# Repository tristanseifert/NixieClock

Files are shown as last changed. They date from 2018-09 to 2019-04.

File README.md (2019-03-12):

# Nixie Clock
A Nixie tube clock based on the Russian [IN-12A](http://www.tube-tester.com/sites/nixie/data/in-12a.htm) tubes. The clock is designed to be modular: one or more tube boards (which contain value latches, high voltage drivers, tube mounts, and current limiting resistors) can be connected to the control board (which contains a full 68008-based minicomputer!)

There is also provision for an USB FIFO (FT245R) for communication with a PC, a 32K NVRAM+RTC (DS1244) for timekeeping and configuration, a 100Hz periodic interrupt, and a connection to a Noritake CU24043-Y100 (or any other display with the same pinout) VFD.

The board is powered off of a regulated 12V supply, from which 5V and ~180V (for the anodes) is generated.

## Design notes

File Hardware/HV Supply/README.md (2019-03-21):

# Nixie Clock HV Supply
This power supply is based on Nick de Smith's [Nixie HV Switching PSU](https://www.desmith.net/NMdS/Electronics/NixiePSU.html) and derived from the provided EAGLE files. Modifications were made to use different connectors, and to add Mouser part numbers.

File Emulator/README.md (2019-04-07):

This directory contains source to a simple emulator of the hardware. The emulation is relatively incomplete, and does not emulate some aspects (timings) of the hardware correctly, but it should be good enough to test the basic functioning of code.

It depends on [Musashi](https://github.com/kstenerud/Musashi/) for CPU emulation and disassemblies for logging.

## Usage
Invoke the binary, specifying the required information via these command line flags:

- `-r`: Path to boot ROM file
- `-n`: Path to NVRAM file; created if it doesn't already exist
- `-h`: Prints help

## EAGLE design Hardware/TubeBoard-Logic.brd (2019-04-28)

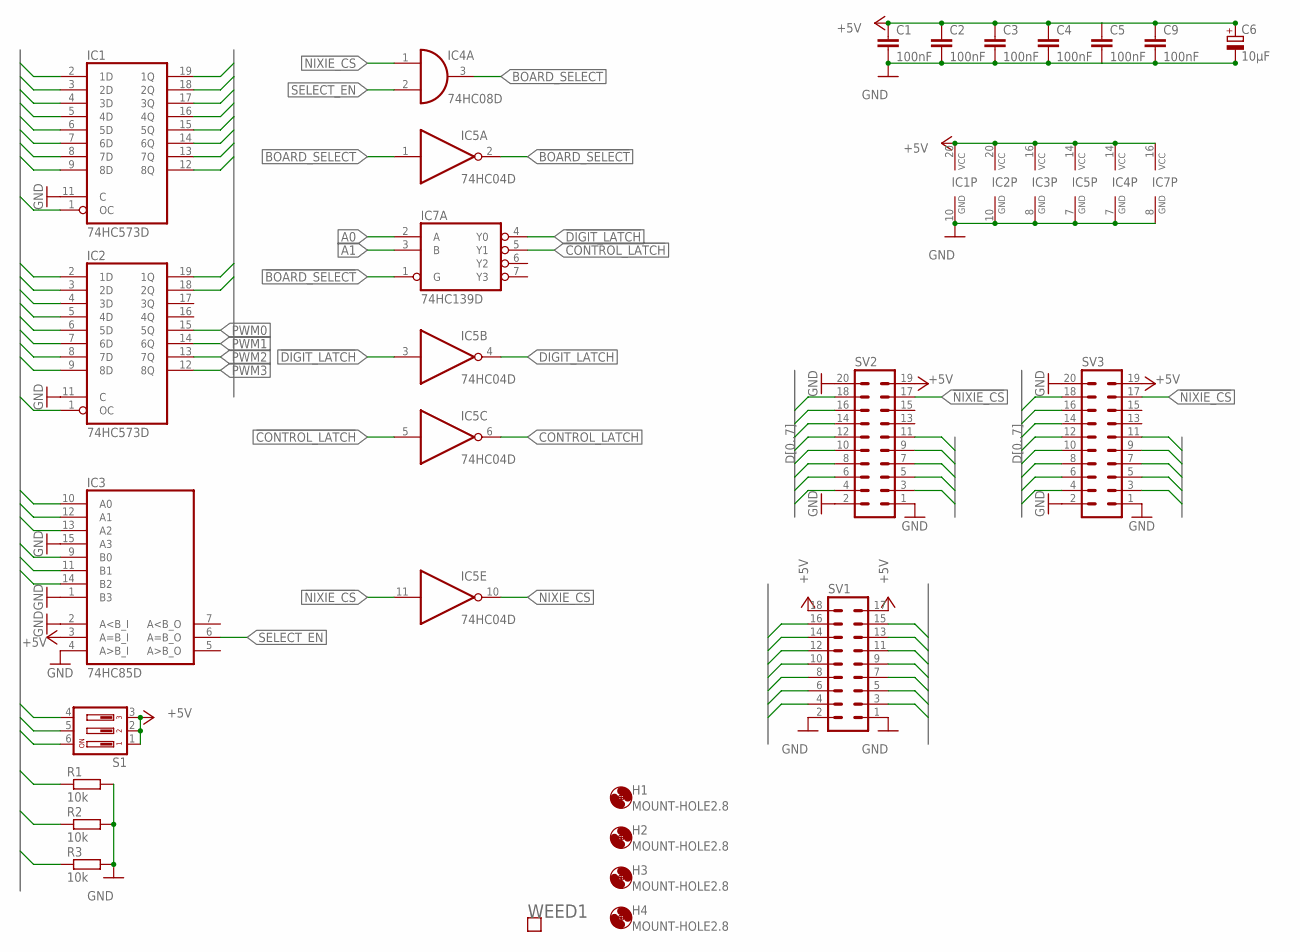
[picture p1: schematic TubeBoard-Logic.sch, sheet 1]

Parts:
C1, C2, C3, C4, C5, C9: 100nF; C1206
C6: 10µF; SMC_B; MOUSER 581-TAJB106K020RNJV
H1, H2, H3, H4: MOUNT-HOLE2.8; 2,8
IC1, IC2: 74HC573D; SO20W
IC3: 74HC85D; SO16; MOUSER 771-74HC85D-T
IC4: 74HC08D; SO14
IC5: 74HC04D; SO14
IC7: 74HC139D; SO16; MOUSER 771-HC139D652
R1, R2, R3: 10k; R2012; MOUSER 652-CR0805FX-1002ELF
S1: SD4-03; MOUSER 611-BDB03
SV1: MA09-2
SV2, SV3: MA10-2
WEED1: WEED; DOINK

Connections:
!BOARD_SELECT: IC5.2 (O), IC7.1 (G)
!CONTROL_LATCH: IC5.5 (I), IC7.5 (Y1)
!DIGIT_LATCH: IC5.3 (I), IC7.4 (Y0)
!NIXIE_CS: IC5.11 (I), SV2.17, SV3.17
+5V: C1.1, C2.1, C3.1, C4.1, C5.1, C6.+, C9.1, IC1.20 (VCC), IC2.20 (VCC), IC3.3 (A=B_I), IC3.16 (VCC), IC4.14 (VCC), IC5.14 (VCC), IC7.16 (VCC), S1.1, S1.2, S1.3, SV1.17, SV1.18, SV2.19, SV3.19
A0: IC7.2 (A), SV2.3, SV3.3
A1: IC7.3 (B), SV2.5, SV3.5
A2: IC3.10 (A0), SV2.7, SV3.7
A3: IC3.12 (A1), SV2.9, SV3.9
A4: IC3.13 (A2), SV2.11, SV3.11
BOARD_SELECT: IC4.3 (O), IC5.1 (I)
COLON_B: IC2.19 (1Q), SV1.8
COLON_T: IC2.18 (2Q), SV1.6
CONTROL_LATCH: IC2.1 (OC), IC5.6 (O)
D0: IC1.2 (1D), IC2.2 (1D), SV2.8, SV3.8
D1: IC1.3 (2D), IC2.3 (2D), SV2.6, SV3.6
D2: IC1.4 (3D), IC2.4 (3D), SV2.4, SV3.4
D3: IC1.5 (4D), IC2.5 (4D), SV2.10, SV3.10
D4: IC1.6 (5D), IC2.6 (5D), SV2.12, SV3.12
D5: IC1.7 (6D), IC2.7 (6D), SV2.14, SV3.14
D6: IC1.8 (7D), IC2.8 (7D), SV2.16, SV3.16
D7: IC1.9 (8D), IC2.9 (8D), SV2.18, SV3.18
DIGIT_LATCH: IC1.1 (OC), IC5.4 (O)
GND: C1.2, C2.2, C3.2, C4.2, C5.2, C6.-, C9.2, IC1.10 (GND), IC1.11 (C), IC2.10 (GND), IC2.11 (C), IC3.1 (B3), IC3.2 (A<B_I), IC3.4 (A>B_I), IC3.8 (GND), IC3.15 (A3), IC4.7 (GND), IC5.7 (GND), IC7.8 (GND), R1.2, R2.2, R3.2, SV1.1, SV1.2, SV2.1, SV2.2, SV2.20, SV3.1, SV3.2, SV3.20; also elsewhere on the board
ID0: IC3.9 (B0), R3.1, S1.6
ID1: IC3.11 (B1), R2.1, S1.5
ID2: IC3.14 (B2), R1.1, S1.4
LDIGIT0: IC1.19 (1Q), SV1.16
LDIGIT1: IC1.18 (2Q), SV1.14
LDIGIT2: IC1.17 (3Q), SV1.12
LDIGIT3: IC1.16 (4Q), SV1.10
NIXIE_CS: IC4.1 (I0), IC5.10 (O)
PWM0: IC2.15 (5Q), SV1.7
PWM1: IC2.14 (6Q), SV1.5
PWM2: IC2.13 (7Q), SV1.3
PWM3: IC2.12 (8Q), SV1.4
RDIGIT0: IC1.15 (5Q), SV1.15
RDIGIT1: IC1.14 (6Q), SV1.13
RDIGIT2: IC1.13 (7Q), SV1.11
RDIGIT3: IC1.12 (8Q), SV1.9
SELECT_EN: IC3.6 (A=B_O), IC4.2 (I1)

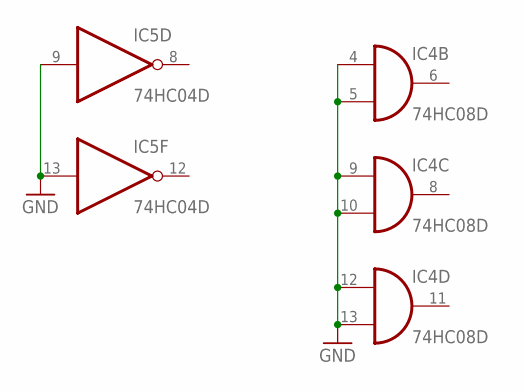
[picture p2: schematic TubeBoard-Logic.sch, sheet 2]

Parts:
IC4: 74HC08D; SO14
IC5: 74HC04D; SO14

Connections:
GND: IC4.4 (I0), IC4.5 (I1), IC4.9 (I0), IC4.10 (I1), IC4.12 (I0), IC4.13 (I1), IC5.9 (I), IC5.13 (I); also elsewhere on the board

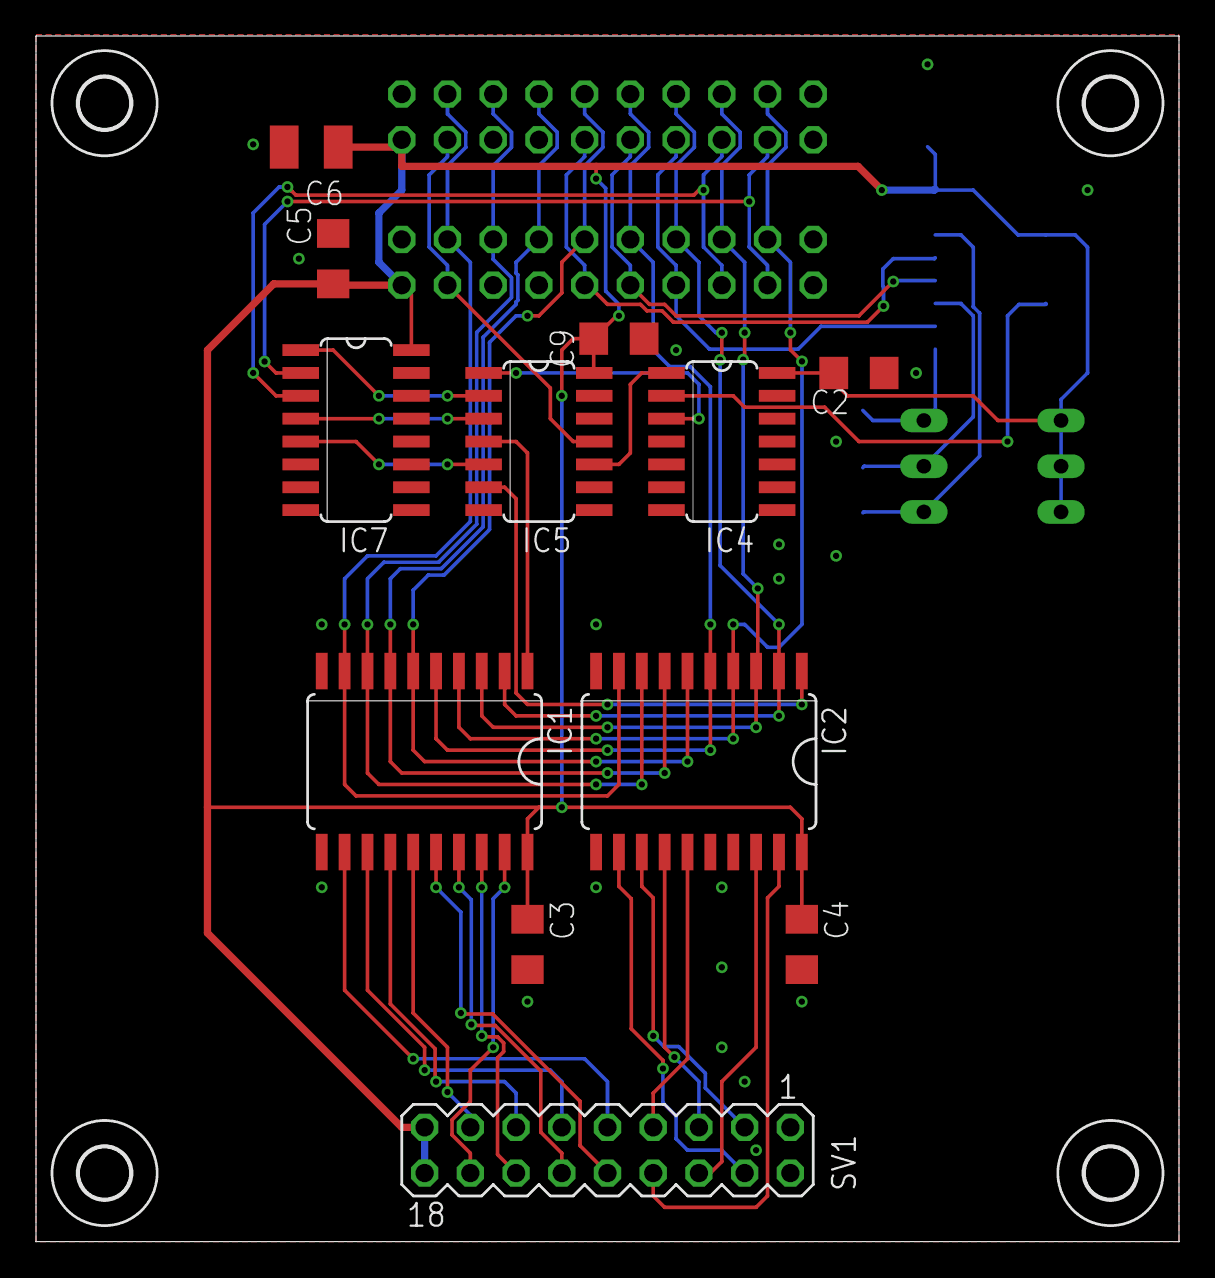
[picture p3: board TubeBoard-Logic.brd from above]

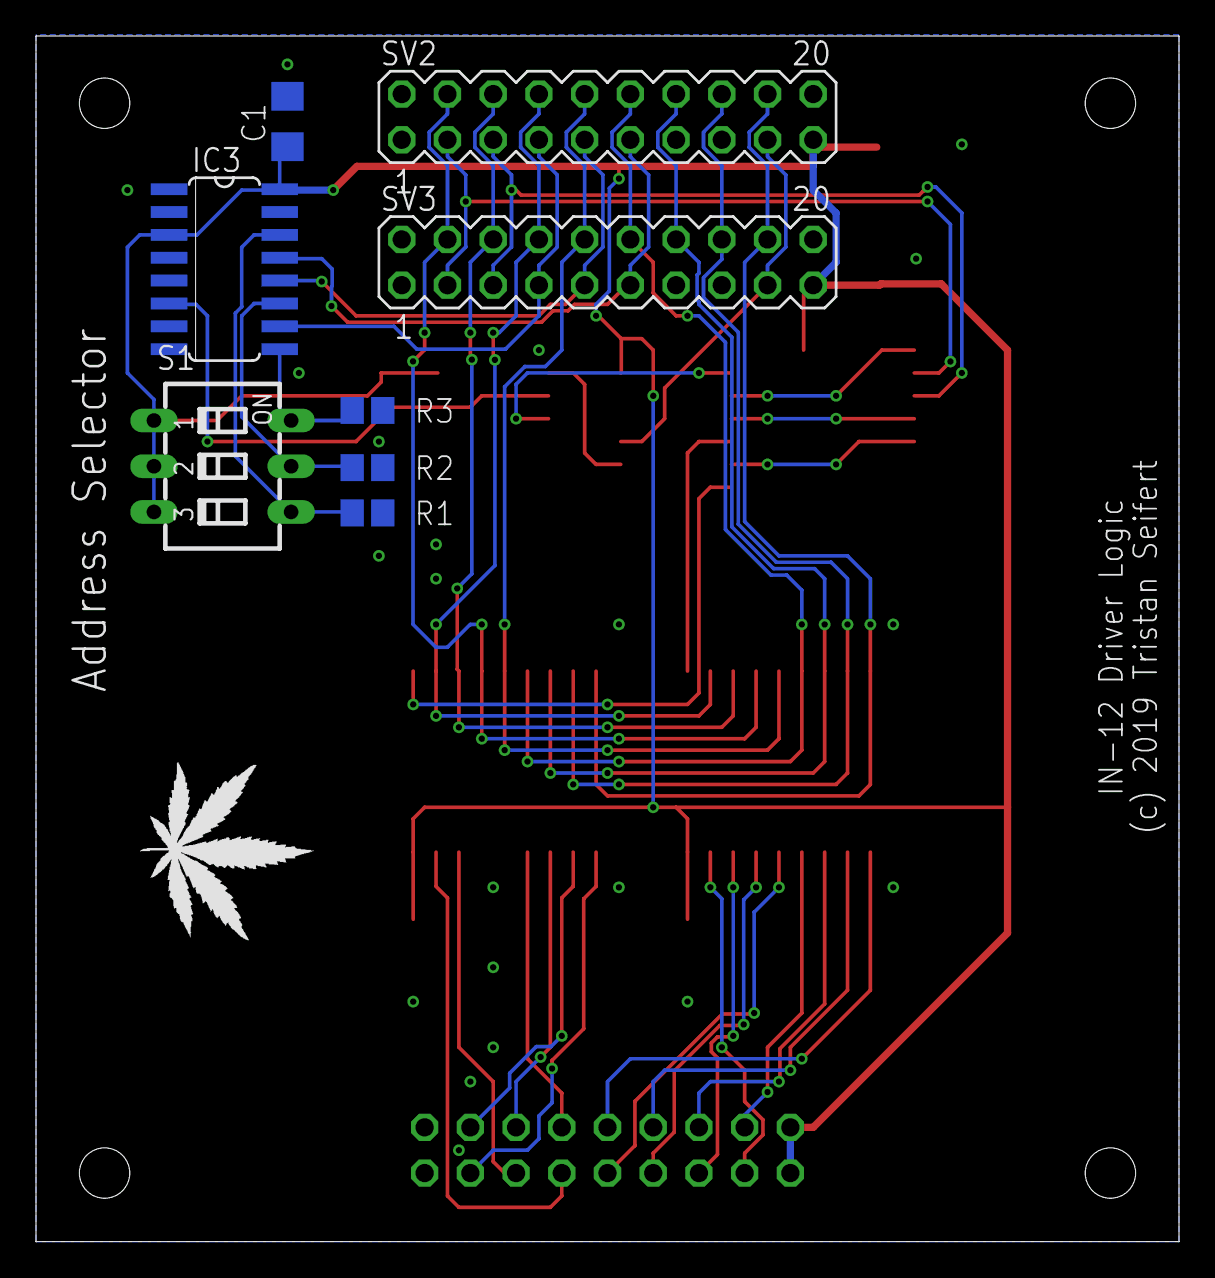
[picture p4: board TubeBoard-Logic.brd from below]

Board: 2 copper layers, 63.5 x 67.0 mm, 25 parts (9 on the bottom side), 41 nets.

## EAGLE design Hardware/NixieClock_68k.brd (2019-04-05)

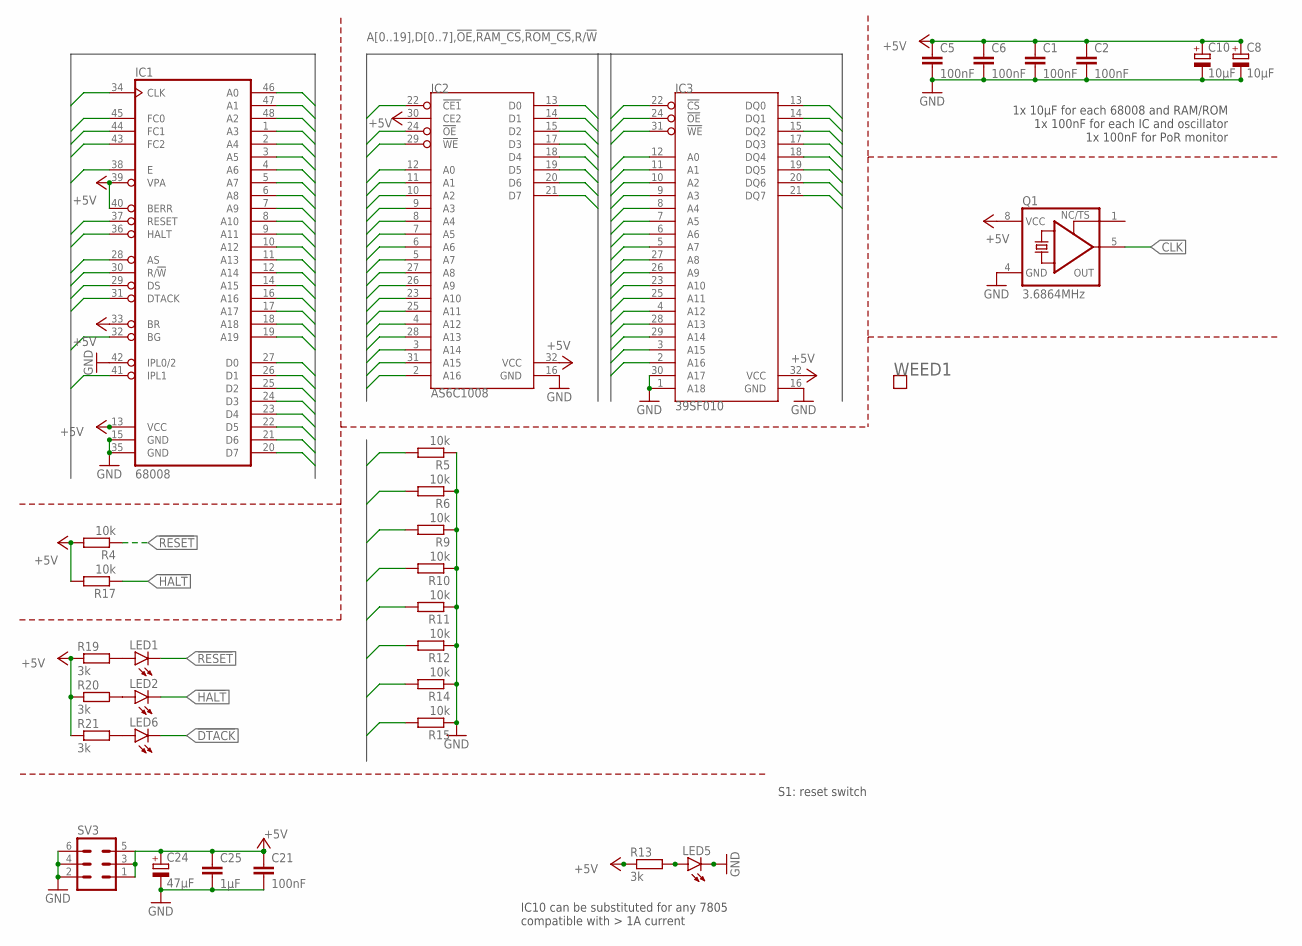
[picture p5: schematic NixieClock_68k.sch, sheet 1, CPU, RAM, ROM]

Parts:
C1, C2, C5, C6, C21: 100nF; C0805; MOUSER 710-885012207072
C8, C10: 10µF; SMC_B; MOUSER 581-TAJB106K020RNJV
C24: 47µF; CT6032; MOUSER 581-TAJD476M016RNJV
C25: 1µF; C0805; MOUSER 710-885012107015
IC1: 68008; DIL48
IC2: AS6C1008; DIL32
IC3: 39SF010; DIL32; MOUSER 804-39SF010A7CPHE
LED1, LED2: LEDCHIPLED_1206; CHIPLED_1206; MOUSER 710-156120RS75300
LED5: LEDCHIPLED_1206; CHIPLED_1206; MOUSER 710-156120YS75300
LED6: LEDCHIPLED_1206; CHIPLED_1206; MOUSER 710-156120VS75300
Q1: 3.6864MHz; DIL08S; MOUSER 774-MXO45HS-3C-3.6
R4, R5, R6, R9, R10, R11, R12, R14, R15, R17: 10k; R2012; MOUSER 652-CR0805FX-1002ELF
R13, R19, R20, R21: 3k; R2012; MOUSER 652-CR0805JW-302ELF
SV3: MA03-2
WEED1: WEED; DOINK

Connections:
!AS: IC1.28 (AS); also elsewhere on the board
!BG: IC1.32 (BG)
!DS: IC1.29 (DS)
!DTACK: IC1.31 (DTACK), LED6.C; also elsewhere on the board
!HALT: IC1.36 (HALT), LED2.C, R17.1; also elsewhere on the board
!IPL1: IC1.41 (IPL1); also elsewhere on the board
!OE: IC2.24 (!OE), IC3.24 (!OE); also elsewhere on the board
!RAM_CS: IC2.22 (!CE1); also elsewhere on the board
!RESET: IC1.37 (RESET), LED1.C, R4.1; also elsewhere on the board
!ROM_CS: IC3.22 (!CS); also elsewhere on the board
+5V: C1.1, C2.1, C5.1, C6.1, C8.+, C10.+, C21.1, C24.+, C25.1, IC1.13 (VCC), IC1.33 (BR), IC1.39 (VPA), IC1.40 (BERR), IC2.30 (CE2), IC2.32 (VCC), IC3.32 (VCC), Q1.8 (VCC), R4.2, R13.1, R17.2, R19.1, R20.1, R21.1, SV3.1, SV3.3, SV3.5; also elsewhere on the board
A0: IC1.46 (A0), IC2.12 (A0), IC3.12 (A0); also elsewhere on the board
A1: IC1.47 (A1), IC2.11 (A1), IC3.11 (A1); also elsewhere on the board
A2: IC1.48 (A2), IC2.10 (A2), IC3.10 (A2); also elsewhere on the board
A3: IC1.1 (A3), IC2.9 (A3), IC3.9 (A3); also elsewhere on the board
A4: IC1.2 (A4), IC2.8 (A4), IC3.8 (A4); also elsewhere on the board
A5: IC1.3 (A5), IC2.7 (A5), IC3.7 (A5); also elsewhere on the board
A6: IC1.4 (A6), IC2.6 (A6), IC3.6 (A6); also elsewhere on the board
A7: IC1.5 (A7), IC2.5 (A7), IC3.5 (A7); also elsewhere on the board
A8: IC1.6 (A8), IC2.27 (A8), IC3.27 (A8); also elsewhere on the board
A9: IC1.7 (A9), IC2.26 (A9), IC3.26 (A9); also elsewhere on the board
A10: IC1.8 (A10), IC2.23 (A10), IC3.23 (A10); also elsewhere on the board
A11: IC1.9 (A11), IC2.25 (A11), IC3.25 (A11); also elsewhere on the board
A12: IC1.10 (A12), IC2.4 (A12), IC3.4 (A12); also elsewhere on the board
A13: IC1.11 (A13), IC2.28 (A13), IC3.28 (A13); also elsewhere on the board
A14: IC1.12 (A14), IC2.3 (A14), IC3.29 (A14); also elsewhere on the board
A15: IC1.14 (A15), IC2.31 (A15), IC3.3 (A15)
A16: IC1.16 (A16), IC2.2 (A16), IC3.2 (A16); also elsewhere on the board
A17: IC1.17 (A17); also elsewhere on the board
A18: IC1.18 (A18); also elsewhere on the board
A19: IC1.19 (A19)
CLK: IC1.34 (CLK), Q1.5 (OUT); also elsewhere on the board
D0: IC1.27 (D0), IC2.13 (D0), IC3.13 (DQ0), R5.2; also elsewhere on the board
D1: IC1.26 (D1), IC2.14 (D1), IC3.14 (DQ1), R6.2; also elsewhere on the board
D2: IC1.25 (D2), IC2.15 (D2), IC3.15 (DQ2), R9.2; also elsewhere on the board
D3: IC1.24 (D3), IC2.17 (D3), IC3.17 (DQ3), R10.2; also elsewhere on the board
D4: IC1.23 (D4), IC2.18 (D4), IC3.18 (DQ4), R11.2; also elsewhere on the board
D5: IC1.22 (D5), IC2.19 (D5), IC3.19 (DQ5), R12.2; also elsewhere on the board
D6: IC1.21 (D6), IC2.20 (D6), IC3.20 (DQ6), R14.2; also elsewhere on the board
D7: IC1.20 (D7), IC2.21 (D7), IC3.21 (DQ7), R15.2; also elsewhere on the board
E: IC1.38 (E)
FC0: IC1.45 (FC0); also elsewhere on the board
FC1: IC1.44 (FC1); also elsewhere on the board
FC2: IC1.43 (FC2); also elsewhere on the board
GND: C1.2, C2.2, C5.2, C6.2, C8.-, C10.-, C21.2, C24.-, C25.2, IC1.15 (GND), IC1.35 (GND), IC1.42 (IPL0/2), IC2.16 (GND), IC3.1 (A18), IC3.16 (GND), IC3.30 (A17), LED5.C, Q1.4 (GND), R5.1, R6.1, R9.1, R10.1, R11.1, R12.1, R14.1, R15.1, SV3.2, SV3.4, SV3.6; also elsewhere on the board
unnamed: LED1.A, R19.2
unnamed: LED5.A, R13.2
unnamed: LED2.A, R20.2
unnamed: LED6.A, R21.2
R/!W!: IC1.30 (R/!W), IC2.29 (!WE), IC3.31 (!WE); also elsewhere on the board

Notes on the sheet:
1x 10µF for each 68008 and RAM/ROM 1x 100nF for each IC and oscillator 1x 100nF for PoR monitor
IC10 can be substituted for any 7805 compatible with > 1A current
S1: reset switch

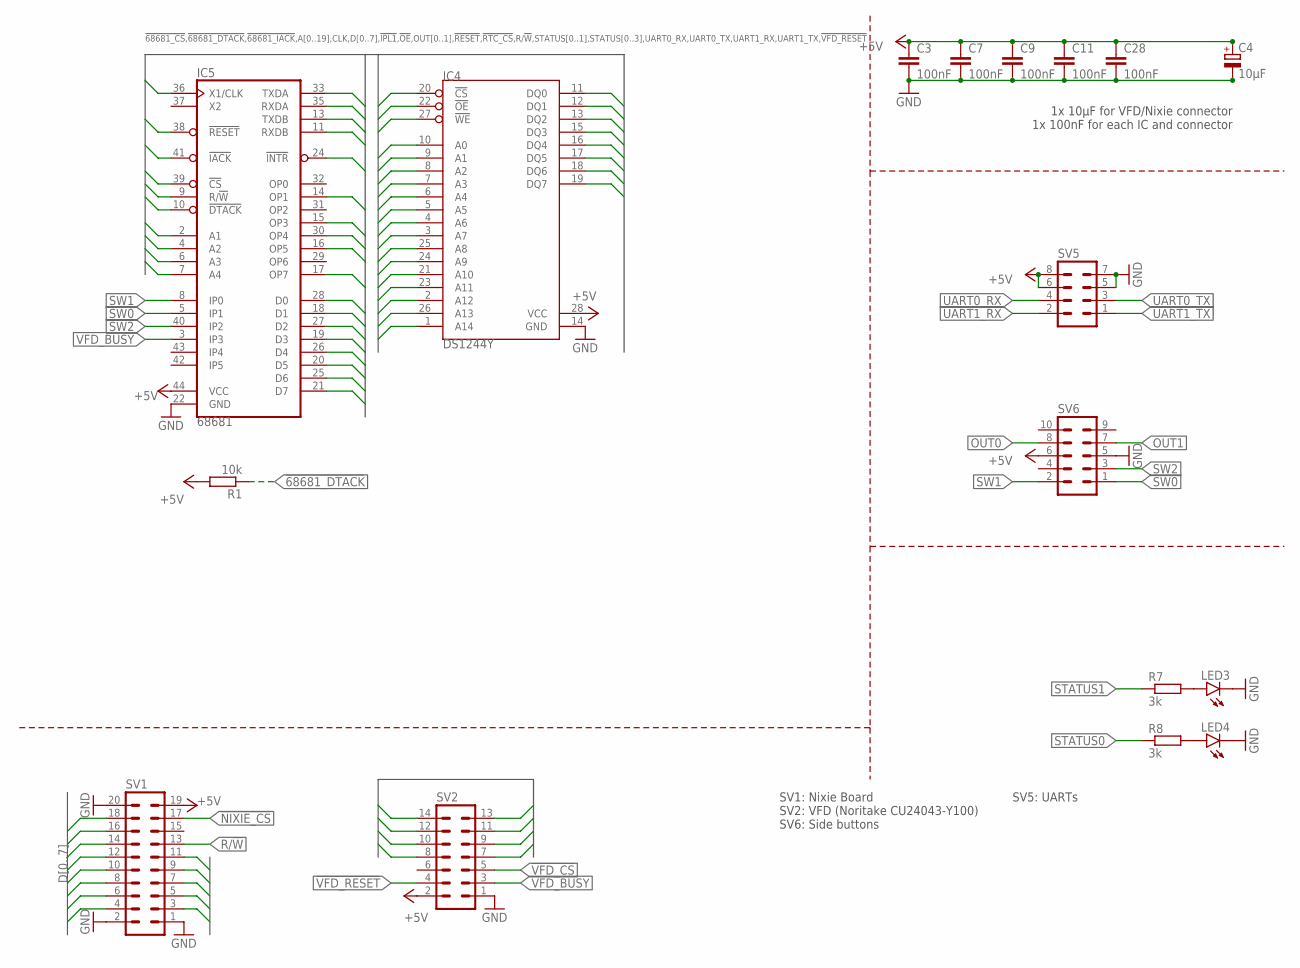
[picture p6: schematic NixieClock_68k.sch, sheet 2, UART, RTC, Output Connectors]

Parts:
C3, C7, C9, C11, C28: 100nF; C0805; MOUSER 710-885012207072
C4: 10µF; SMC_B; MOUSER 581-TAJB106K020RNJV
IC4: DS1244Y; DIL28-6
IC5: 68681; PLCC-S44
LED3, LED4: LEDCHIPLED_1206; CHIPLED_1206; MOUSER 710-156120VS75300
R1: 10k; R2012; MOUSER 652-CR0805FX-1002ELF
R7, R8: 3k; R2012; MOUSER 652-CR0805JW-302ELF
SV1: MA10-2
SV2: MA07-2
SV5: MA04-2
SV6: MA05-2

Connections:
!68681_CS: IC5.39 (!CS); also elsewhere on the board
!68681_DTACK: IC5.10 (!DTACK), R1.1; also elsewhere on the board
!68681_IACK: IC5.41 (!IACK); also elsewhere on the board
!IPL1: IC5.24 (!INTR); also elsewhere on the board
!NIXIE_CS: SV1.17; also elsewhere on the board
!OE: IC4.22 (!OE); also elsewhere on the board
!RESET: IC5.38 (!RESET); also elsewhere on the board
!RTC_CS: IC4.20 (!CS); also elsewhere on the board
!VFD_CS: SV2.5; also elsewhere on the board
!VFD_RESET: IC5.30 (OP4), SV2.4
+5V: C3.1, C4.+, C7.1, C9.1, C11.1, C28.1, IC4.28 (VCC), IC5.44 (VCC), R1.2, SV1.19, SV2.2, SV5.6, SV5.8, SV6.6; also elsewhere on the board
A0: IC4.10 (A0), IC5.2 (A1), SV1.3; also elsewhere on the board
A1: IC4.9 (A1), IC5.4 (A2), SV1.5; also elsewhere on the board
A2: IC4.8 (A2), IC5.6 (A3), SV1.7; also elsewhere on the board
A3: IC4.7 (A3), IC5.7 (A4), SV1.9; also elsewhere on the board
A4: IC4.6 (A4), SV1.11; also elsewhere on the board
A5: IC4.5 (A5); also elsewhere on the board
A6: IC4.4 (A6); also elsewhere on the board
A7: IC4.3 (A7); also elsewhere on the board
A8: IC4.25 (A8); also elsewhere on the board
A9: IC4.24 (A9); also elsewhere on the board
A10: IC4.21 (A10); also elsewhere on the board
A11: IC4.23 (A11); also elsewhere on the board
A12: IC4.2 (A12); also elsewhere on the board
A13: IC4.26 (A13); also elsewhere on the board
A14: IC4.1 (A14); also elsewhere on the board
CLK: IC5.36 (X1/CLK); also elsewhere on the board
D0: IC4.11 (DQ0), IC5.28 (D0), SV1.8, SV2.7; also elsewhere on the board
D1: IC4.12 (DQ1), IC5.18 (D1), SV1.6, SV2.8; also elsewhere on the board
D2: IC4.13 (DQ2), IC5.27 (D2), SV1.4, SV2.9; also elsewhere on the board
D3: IC4.15 (DQ3), IC5.19 (D3), SV1.10, SV2.10; also elsewhere on the board
D4: IC4.16 (DQ4), IC5.26 (D4), SV1.12, SV2.11; also elsewhere on the board
D5: IC4.17 (DQ5), IC5.20 (D5), SV1.14, SV2.12; also elsewhere on the board
D6: IC4.18 (DQ6), IC5.25 (D6), SV1.16, SV2.13; also elsewhere on the board
D7: IC4.19 (DQ7), IC5.21 (D7), SV1.18, SV2.14; also elsewhere on the board
GND: C3.2, C4.-, C7.2, C9.2, C11.2, C28.2, IC4.14 (GND), IC5.22 (GND), LED3.C, LED4.C, SV1.1, SV1.2, SV1.20, SV2.1, SV5.5, SV5.7, SV6.5; also elsewhere on the board
unnamed: LED3.A, R7.2
unnamed: LED4.A, R8.2
OUT0: IC5.15 (OP3), SV6.8
OUT1: IC5.14 (OP1), SV6.7
R/!W!: IC4.27 (!WE), IC5.9 (R/!W), SV1.13; also elsewhere on the board
STATUS0: IC5.17 (OP7), R8.1
STATUS1: IC5.16 (OP5), R7.1
SW0: IC5.5 (IP1), SV6.1
SW1: IC5.8 (IP0), SV6.2
SW2: IC5.40 (IP2), SV6.3
UART0_RX: IC5.35 (RXDA), SV5.4
UART0_TX: IC5.33 (TXDA), SV5.3
UART1_RX: IC5.11 (RXDB), SV5.2
UART1_TX: IC5.13 (TXDB), SV5.1
VFD_BUSY: IC5.3 (IP3), SV2.3

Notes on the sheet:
SV1: Nixie Board SV2: VFD (Noritake CU24043-Y100) SV6: Side buttons
1x 10µF for VFD/Nixie connector 1x 100nF for each IC and connector
SV5: UARTs

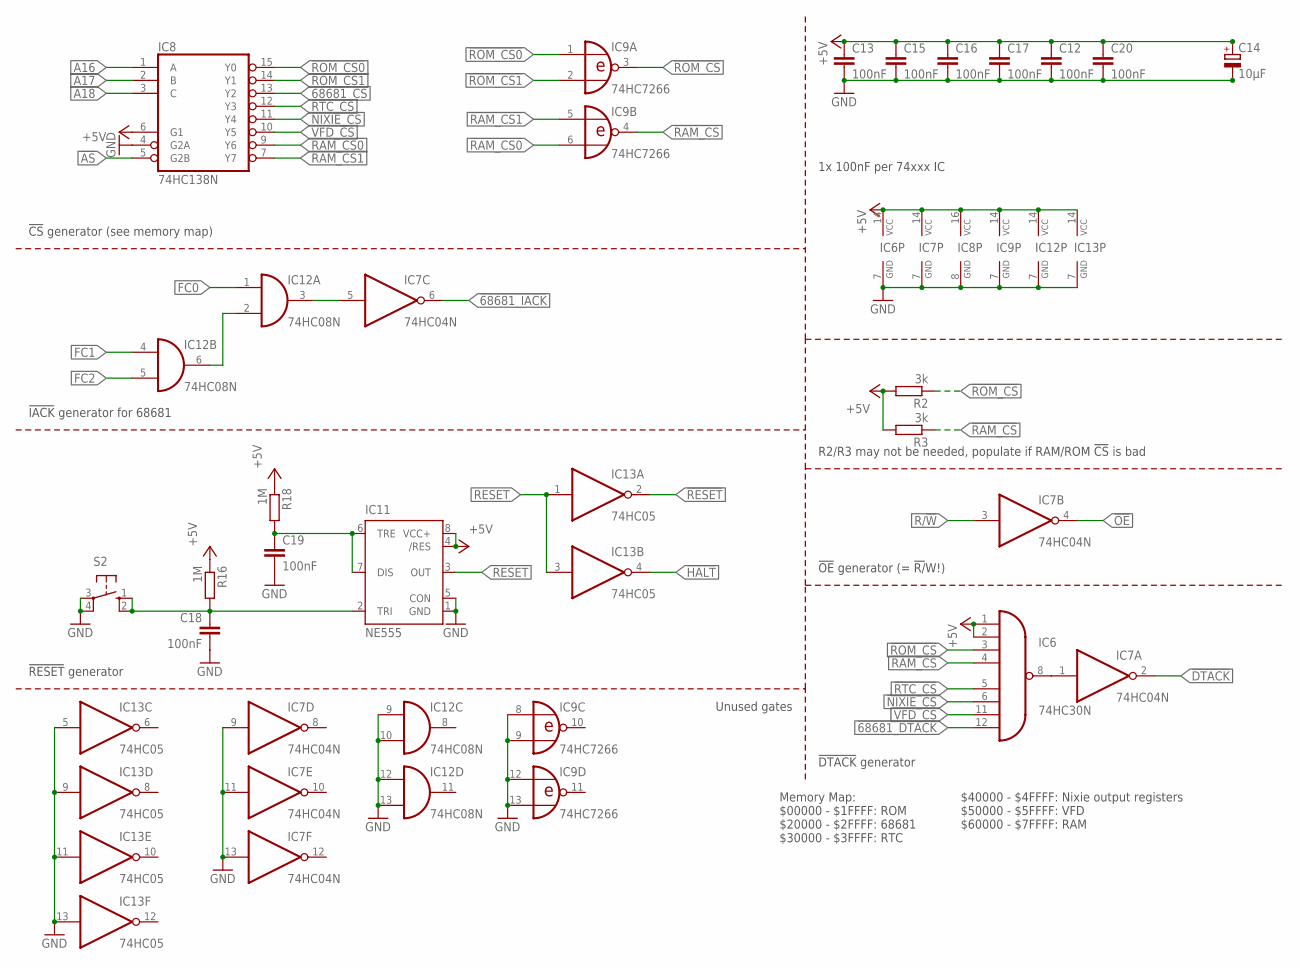
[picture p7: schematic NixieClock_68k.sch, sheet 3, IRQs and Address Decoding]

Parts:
C12, C13, C15, C16, C17, C18, C20: 100nF; C0805; MOUSER 710-885012207072
C14: 10µF; SMC_B; MOUSER 581-TAJB106K020RNJV
C19: 100nF; C0805; MOUSER 710-885012207078
IC6: 74HC30N; DIL14; MOUSER 595-CD74HC30E
IC7: 74HC04N; DIL14; MOUSER 595-SN74HC04AN
IC8: 74HC138N; DIL16; MOUSER 595-SN74HC138N
IC9: 74HC7266; DIL14; MOUSER 595-CD74HC7266E
IC11: NE555; DIL-08; MOUSER 595-NE555P
IC12: 74HC08N; DIL14; MOUSER 595-SN74HC08AN
IC13: 74HC05; DIL14; MOUSER 595-SN74HC05N
R2, R3: 3k; R2012; MOUSER 652-CR0805JW-302ELF
R16, R18: 1M; R2012; MOUSER 652-CR0805FX-18R2ELF
S2: 10-XX; B3F-10XX; MOUSER 653-B3F-1052

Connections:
!68681_CS: IC8.13 (Y2); also elsewhere on the board
!68681_DTACK: IC6.12 (I7); also elsewhere on the board
!68681_IACK: IC7.6 (O); also elsewhere on the board
!AS: IC8.5 (G2B); also elsewhere on the board
!DTACK: IC7.2 (O); also elsewhere on the board
!HALT: IC13.4 (O); also elsewhere on the board
!NIXIE_CS: IC6.6 (I5), IC8.11 (Y4); also elsewhere on the board
!OE: IC7.4 (O); also elsewhere on the board
!RAM_CS: IC6.4 (I3), IC9.4 (O), R3.1; also elsewhere on the board
!RAM_CS0: IC8.9 (Y6), IC9.6 (I1)
!RAM_CS1: IC8.7 (Y7), IC9.5 (I0)
!RESET: IC13.2 (O); also elsewhere on the board
!ROM_CS: IC6.3 (I2), IC9.3 (O), R2.1; also elsewhere on the board
!ROM_CS0: IC8.15 (Y0), IC9.1 (I0)
!ROM_CS1: IC8.14 (Y1), IC9.2 (I1)
!RTC_CS: IC6.5 (I4), IC8.12 (Y3); also elsewhere on the board
!VFD_CS: IC6.11 (I6), IC8.10 (Y5); also elsewhere on the board
+5V: C12.1, C13.1, C14.+, C15.1, C16.1, C17.1, C20.1, IC6.1 (I0), IC6.2 (I1), IC6.14 (VCC), IC7.14 (VCC), IC8.6 (G1), IC8.16 (VCC), IC9.14 (VCC), IC11.4 (/RES), IC11.8 (VCC+), IC12.14 (VCC), IC13.14 (VCC), R2.2, R3.2, R16.1, R18.1; also elsewhere on the board
A16: IC8.1 (A); also elsewhere on the board
A17: IC8.2 (B); also elsewhere on the board
A18: IC8.3 (C); also elsewhere on the board
FC0: IC12.1 (I0); also elsewhere on the board
FC1: IC12.4 (I0); also elsewhere on the board
FC2: IC12.5 (I1); also elsewhere on the board
GND: C12.2, C13.2, C14.-, C15.2, C16.2, C17.2, C18.2, C19.2, C20.2, IC6.7 (GND), IC7.7 (GND), IC7.9 (I), IC7.11 (I), IC7.13 (I), IC8.4 (G2A), IC8.8 (GND), IC9.7 (GND), IC9.8 (I0), IC9.9 (I1), IC9.12 (I0), IC9.13 (I1), IC11.1 (GND), IC11.5 (CON), IC12.7 (GND), IC12.9 (I0), IC12.10 (I1), IC12.12 (I0), IC12.13 (I1), IC13.5 (I), IC13.7 (GND), IC13.9 (I), IC13.11 (I), IC13.13 (I), S2.3, S2.4 (P1); also elsewhere on the board
unnamed: C18.1, IC11.2 (TRI), R16.2, S2.1 (S), S2.2 (S1)
unnamed: IC6.8 (O), IC7.1 (I)
unnamed: IC7.5 (I), IC12.3 (O)
unnamed: IC12.2 (I1), IC12.6 (O)
unnamed: C19.1, IC11.6 (TRE), IC11.7 (DIS), R18.2
R/!W!: IC7.3 (I); also elsewhere on the board
RESET: IC11.3 (OUT), IC13.1 (I), IC13.3 (I)

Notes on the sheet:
Memory Map: $00000 - $1FFFF: ROM $20000 - $2FFFF: 68681 $30000 - $3FFFF: RTC
1x 100nF per 74xxx IC
!DTACK! generator
!OE! generator (= !R/!W!)
!CS! generator (see memory map)
!IACK! generator for 68681
$40000 - $4FFFF: Nixie output registers $50000 - $5FFFF: VFD $60000 - $7FFFF: RAM
!RESET! generator
Unused gates
R2/R3 may not be needed, populate if RAM/ROM !CS! is bad

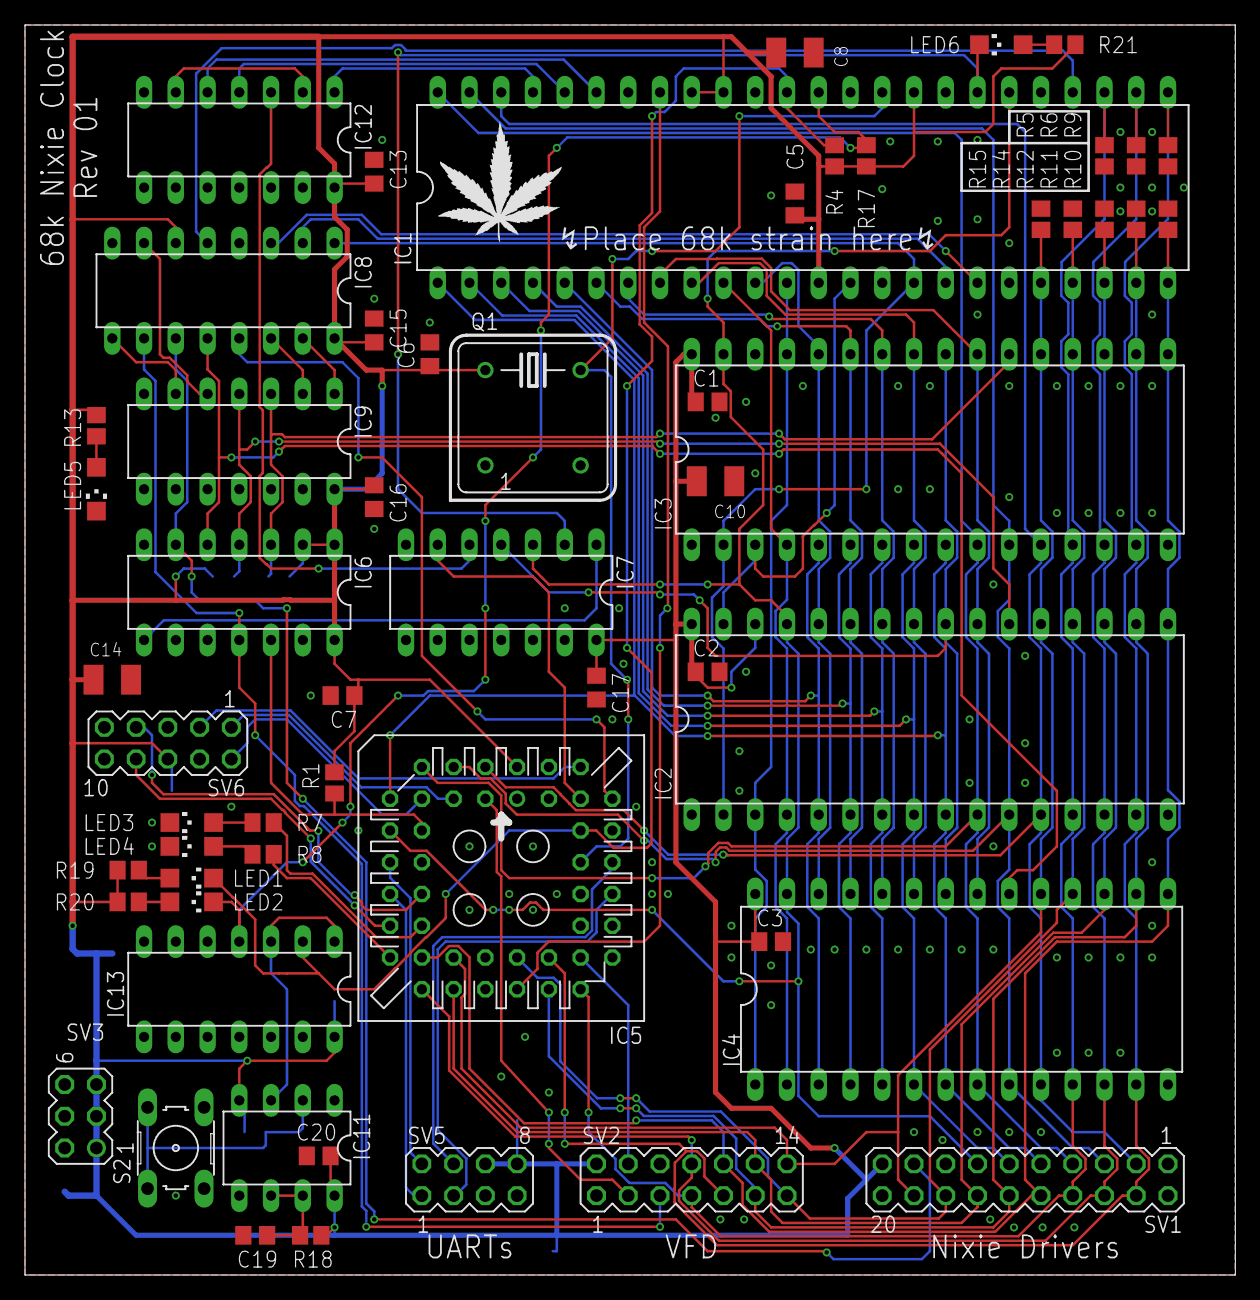
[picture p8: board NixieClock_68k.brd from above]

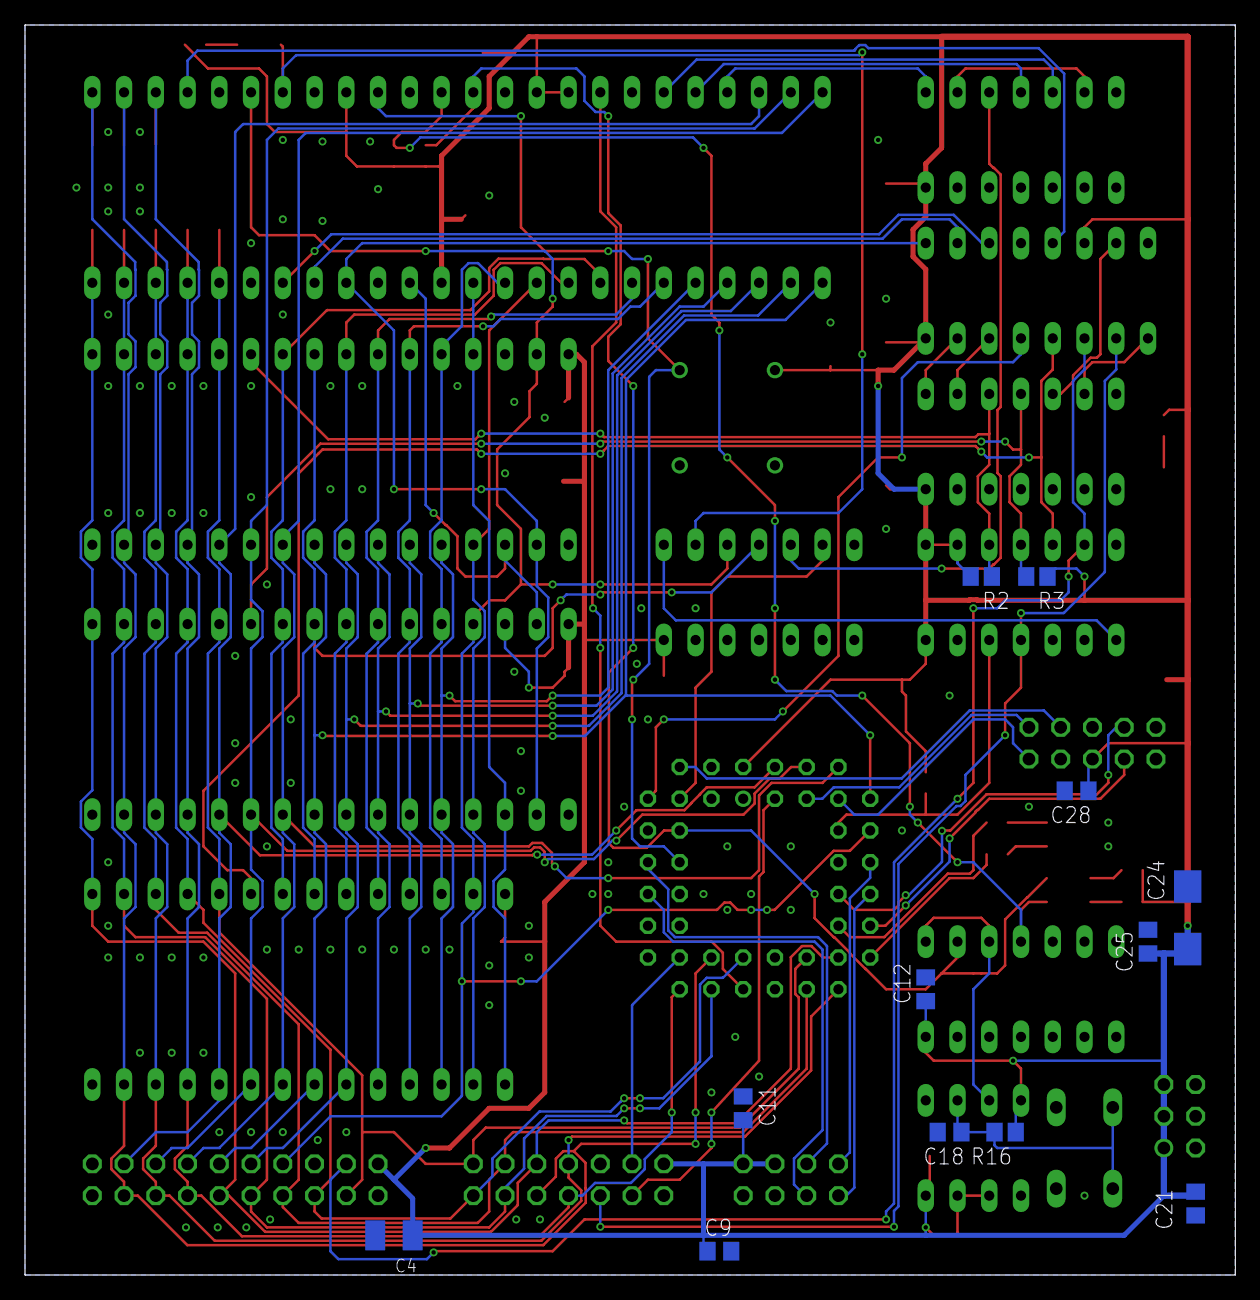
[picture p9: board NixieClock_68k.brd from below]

Board: 2 copper layers, 96.8 x 100.0 mm, 71 parts (12 on the bottom side), 77 nets.

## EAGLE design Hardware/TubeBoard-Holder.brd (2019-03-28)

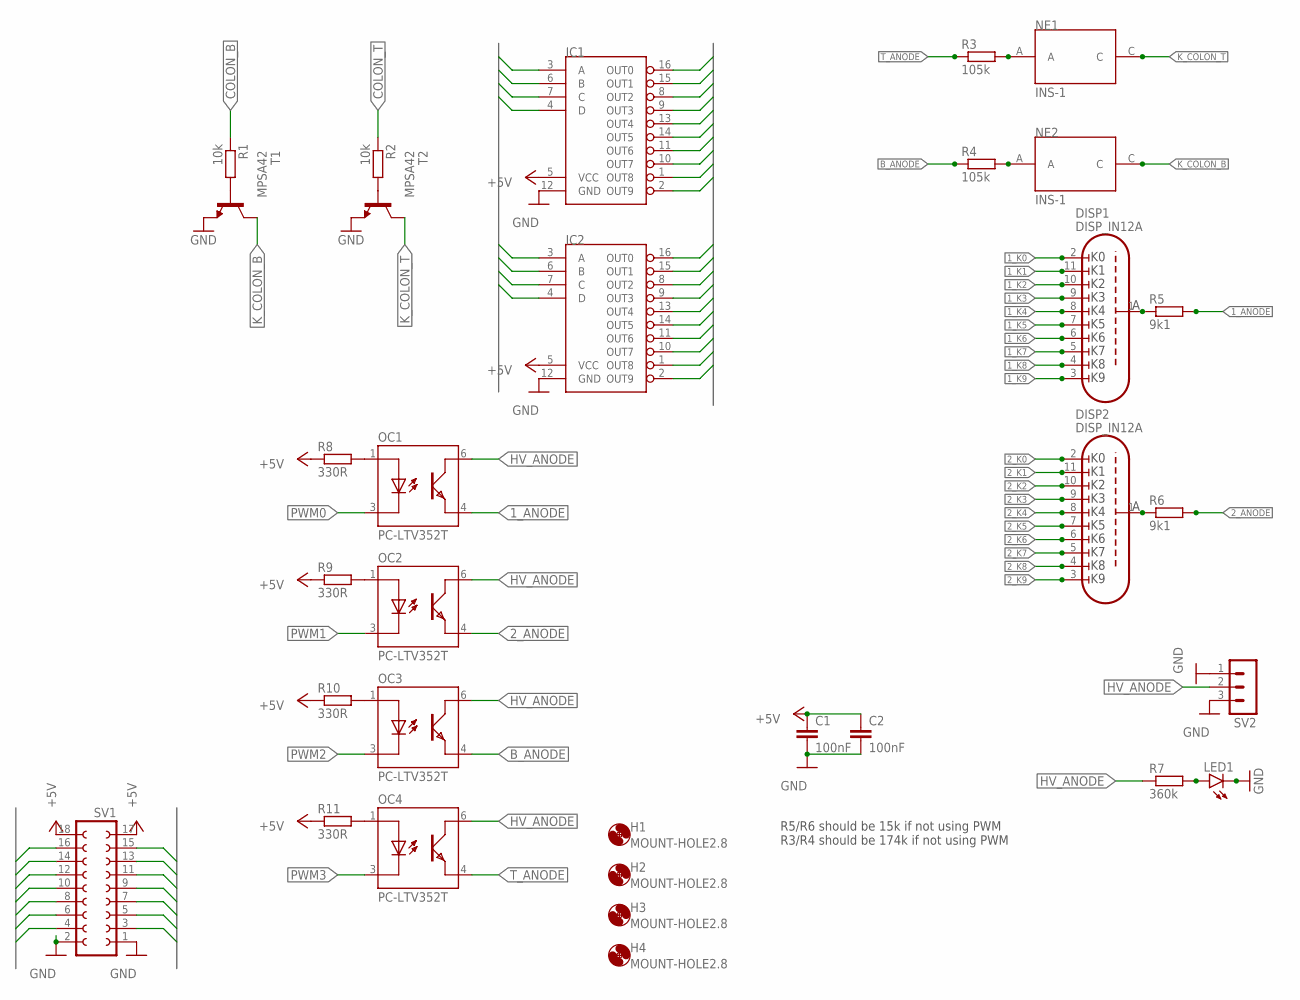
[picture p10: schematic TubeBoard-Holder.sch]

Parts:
C1, C2: 100nF; C1206
DISP1, DISP2: DISP_IN12A; DISP_IN-12_SOCKET
H1, H2, H3, H4: MOUNT-HOLE2.8; 2,8
IC1, IC2: 7441DIL16; DIL16
LED1: LEDCHIPLED_1206; CHIPLED_1206; MOUSER 710-156120RS75300
NE1, NE2: INS-1
OC1, OC2, OC3, OC4: PC-LTV352T; MINIFLAT4; MOUSER 859-LTV-352T
R1, R2: 10k; R2012; MOUSER 652-CR0805FX-1002ELF
R3, R4: 105k; M1206; MOUSER 667-ERJ-8ENF1053V
R5, R6: 9k1; 0411/12
R7: 360k; R2012; MOUSER 652-CR0805-JW-364ELF
R8, R9, R10, R11: 330R; R2012; MOUSER 652-CR0805FX-3300ELF
SV1: FE09-2
SV2: MA03-1
T1, T2: MPSA42; TO92-EBC; MOUSER 833-MPSA42-AP

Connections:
1_ANODE: OC1.4 (TE), R5.2
1_K0: DISP1.2 (K0), IC1.16 (OUT0)
1_K1: DISP1.11 (K1), IC1.15 (OUT1)
1_K2: DISP1.10 (K2), IC1.8 (OUT2)
1_K3: DISP1.9 (K3), IC1.9 (OUT3)
1_K4: DISP1.8 (K4), IC1.13 (OUT4)
1_K5: DISP1.7 (K5), IC1.14 (OUT5)
1_K6: DISP1.6 (K6), IC1.11 (OUT6)
1_K7: DISP1.5 (K7), IC1.10 (OUT7)
1_K8: DISP1.4 (K8), IC1.1 (OUT8)
1_K9: DISP1.3 (K9), IC1.2 (OUT9)
2_ANODE: OC2.4 (TE), R6.2
2_K0: DISP2.2 (K0), IC2.16 (OUT0)
2_K1: DISP2.11 (K1), IC2.15 (OUT1)
2_K2: DISP2.10 (K2), IC2.8 (OUT2)
2_K3: DISP2.9 (K3), IC2.9 (OUT3)
2_K4: DISP2.8 (K4), IC2.13 (OUT4)
2_K5: DISP2.7 (K5), IC2.14 (OUT5)
2_K6: DISP2.6 (K6), IC2.11 (OUT6)
2_K7: DISP2.5 (K7), IC2.10 (OUT7)
2_K8: DISP2.4 (K8), IC2.1 (OUT8)
2_K9: DISP2.3 (K9), IC2.2 (OUT9)
+5V: C1.1, C2.1, IC1.5 (VCC), IC2.5 (VCC), R8.1, R9.1, R10.1, R11.1, SV1.17, SV1.18
B_ANODE: OC3.4 (TE), R4.1
COLON_B: R1.1, SV1.8
COLON_T: R2.1, SV1.6
GND: C1.2, C2.2, IC1.12 (GND), IC2.12 (GND), LED1.C, SV1.1, SV1.2, SV2.1, SV2.3, T1.E, T2.E
HV_ANODE: OC1.6 (TC), OC2.6 (TC), OC3.6 (TC), OC4.6 (TC), R7.1, SV2.2
K_COLON_B: NE2.C, T1.C
K_COLON_T: NE1.C, T2.C
LDIGIT0: IC1.3 (A), SV1.16
LDIGIT1: IC1.6 (B), SV1.14
LDIGIT2: IC1.7 (C), SV1.12
LDIGIT3: IC1.4 (D), SV1.10
unnamed: DISP1.1 (ANODE), R5.1
unnamed: DISP2.1 (ANODE), R6.1
unnamed: NE1.A, R3.2
unnamed: NE2.A, R4.2
unnamed: R1.2, T1.B
unnamed: R2.2, T2.B
unnamed: OC1.1 (A), R8.2
unnamed: LED1.A, R7.2
unnamed: OC2.1 (A), R9.2
unnamed: OC3.1 (A), R10.2
unnamed: OC4.1 (A), R11.2
PWM0: OC1.3 (C), SV1.7
PWM1: OC2.3 (C), SV1.5
PWM2: OC3.3 (C), SV1.3
PWM3: OC4.3 (C), SV1.4
RDIGIT0: IC2.3 (A), SV1.15
RDIGIT1: IC2.6 (B), SV1.13
RDIGIT2: IC2.7 (C), SV1.11
RDIGIT3: IC2.4 (D), SV1.9
T_ANODE: OC4.4 (TE), R3.1

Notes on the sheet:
R5/R6 should be 15k if not using PWM R3/R4 should be 174k if not using PWM

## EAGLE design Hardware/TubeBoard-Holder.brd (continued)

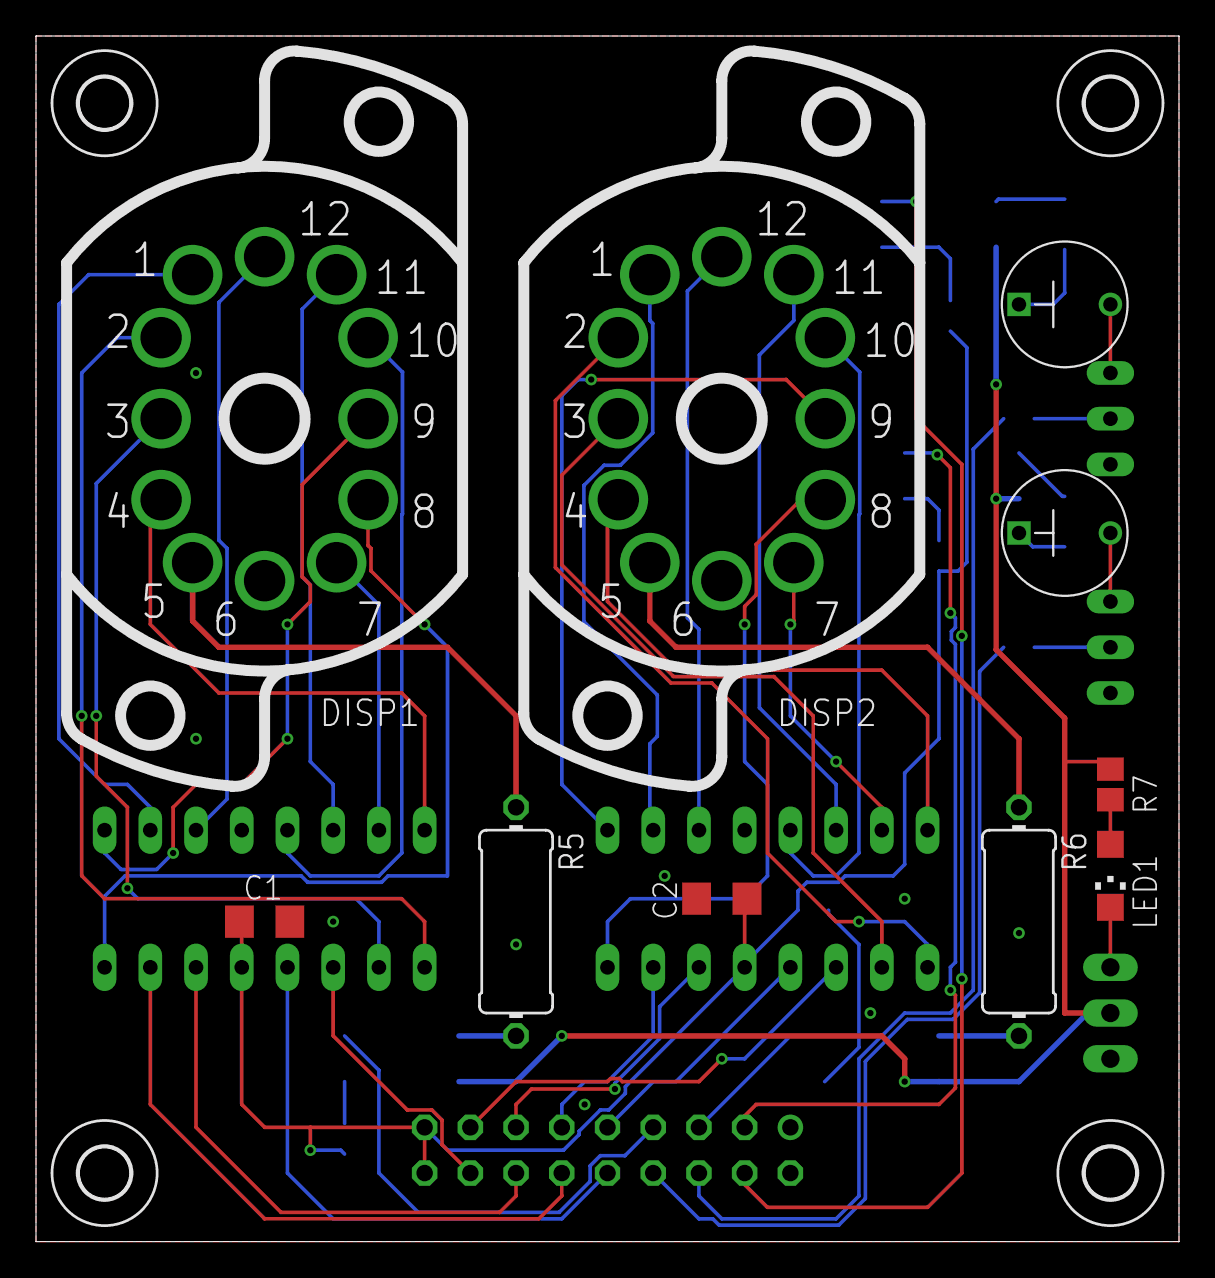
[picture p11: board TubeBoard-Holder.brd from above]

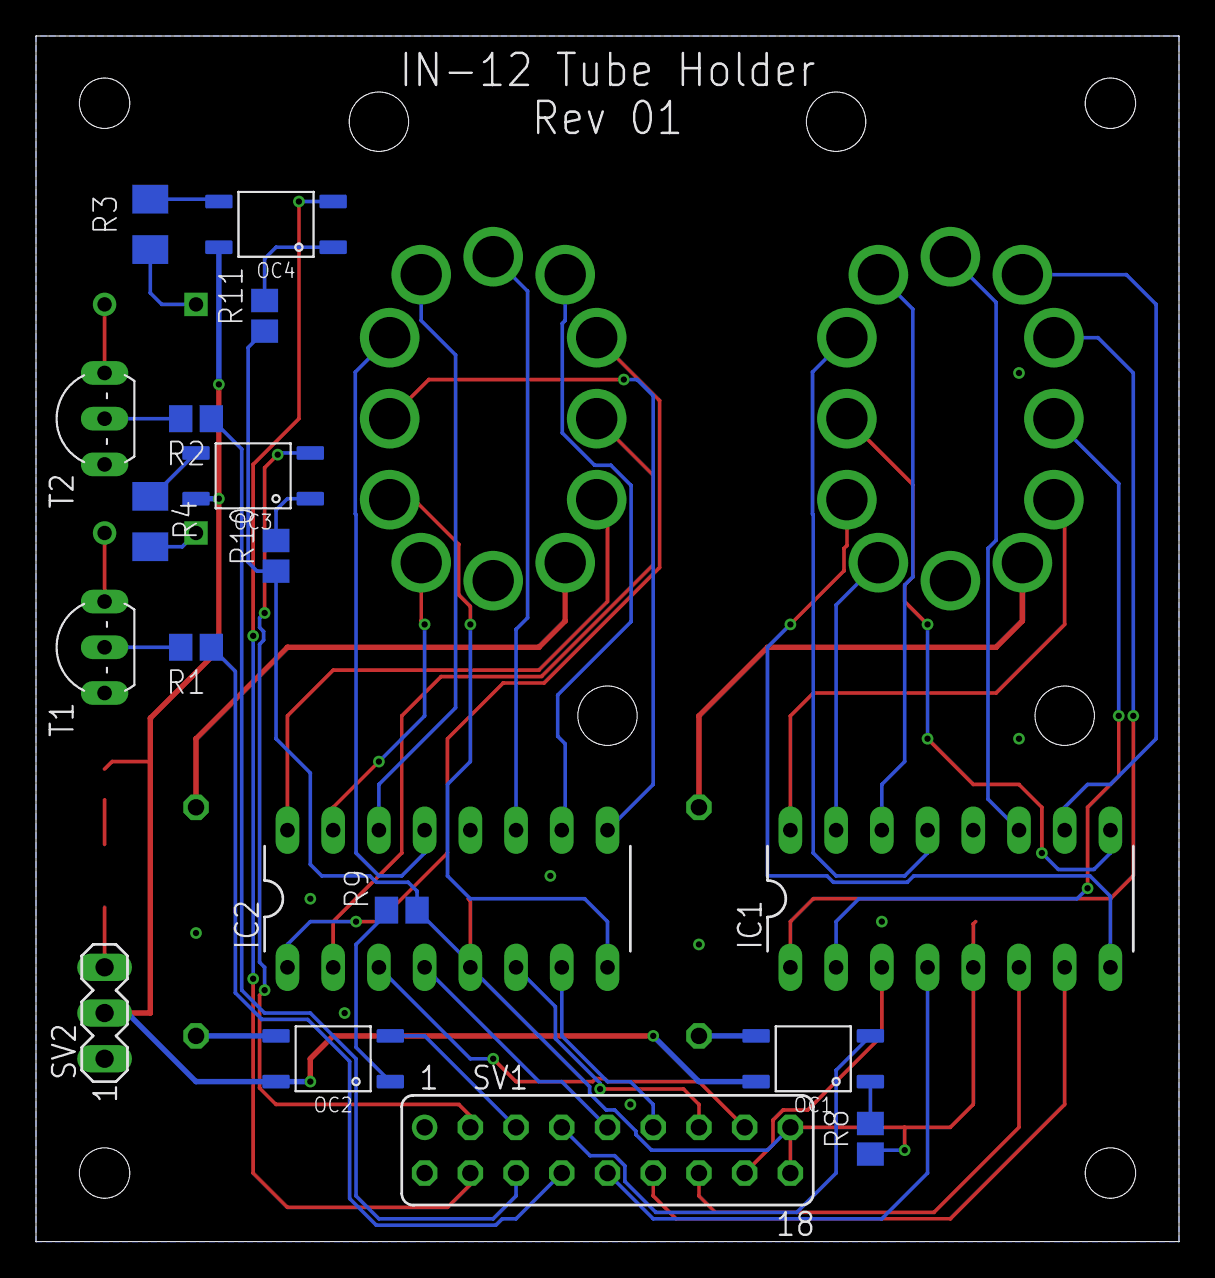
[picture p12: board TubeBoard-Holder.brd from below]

Board: 2 copper layers, 63.5 x 67.0 mm, 32 parts (18 on the bottom side), 54 nets.

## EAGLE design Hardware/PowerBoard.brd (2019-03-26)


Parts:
C101, C102, C103, C104: 2.2µF; C0805; MOUSER 710-885012107016
C105, C106: 100nF; C0805; MOUSER 710-885012207072
C107: 10µF; SMC_B; MOUSER 581-TAJB106K020RNJV
H101, H102, H103: MOUNT-HOLE2.8; 2,8
IC101: MAX232; DIL16; MOUSER 595-MAX232N
S101: DP04; DP-04; MOUSER 611-BDB04
SV101, SV102: MA04-2
X101, X102: F09HPS; F09HP

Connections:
+5V: C105.1, C106.1, C107.+, IC101.16 (VCC), SV102.6, SV102.8; also elsewhere on the board
GND: C103.2, C104.2, C105.2, C106.2, C107.-, IC101.15 (GND), SV101.5, SV101.7, SV102.5, SV102.7, X101.5 (F), X101.G1, X102.5 (F), X102.G1; also elsewhere on the board
unnamed: C104.1, IC101.2 (V+)
unnamed: C103.1, IC101.6 (V-)
unnamed: C102.1, IC101.4 (C2+)
unnamed: C101.1, IC101.1 (C1+)
unnamed: SV101.6, SV101.8
unnamed: IC101.9 (R2OUT), S101.5
unnamed: C102.2, IC101.5 (C2-)
unnamed: C101.2, IC101.3 (C1-)
unnamed: IC101.12 (R1OUT), S101.6
unnamed: IC101.10 (T2IN), S101.7
unnamed: IC101.11 (T1IN), S101.8
SER0_IN: IC101.13 (R1IN), X101.3 (F)
SER0_OUT: IC101.14 (T1OUT), X101.2 (F)
SER1_IN: IC101.8 (R2IN), X102.3 (F)
SER1_OUT: IC101.7 (T2OUT), X102.2 (F)
UART0_RX: S101.3, SV101.4, SV102.4
UART0_TX: S101.1, SV101.3, SV102.3
UART1_RX: S101.4, SV101.2, SV102.2
UART1_TX: S101.2, SV101.1, SV102.1

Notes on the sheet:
X101: UART0 RS232 X102: UART1 RS232
SV101: UART from CPU board SV102: UART at TTL level Use DIP switch S101 to select which UARTs are TTL or RS232 level


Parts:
C201: 100nF; C0805; MOUSER 710-885012207072
C202, C204, C205, C206, C207: 1µF; C0805; MOUSER 710-885012107015
C203: 47µF; CT6032; MOUSER 581-TAJD476M016RNJV
IC201: 7805; TO220V; MOUSER 490-VXO7805-1000
LED201, LED202: LEDCHIPLED_1206; CHIPLED_1206; MOUSER 710-156120YS75300
R201: 10k; R2012; MOUSER 652-CR0805FX-1002ELF
R202: 3k; R2012; MOUSER 652-CR0805JW-302ELF
SV201: 1792863
SV202: MA04-2
SV203, SV204: MA03-2

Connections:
+5V: C203.+, C204.1, C205.1, C206.1, C207.1, IC201.3 (VO), R202.1, SV202.1, SV203.1, SV203.3, SV203.5, SV204.1, SV204.3, SV204.5; also elsewhere on the board
+12V: C201.1, C202.1, IC201.1 (VI), R201.1, SV201.2, SV202.3, SV202.5, SV202.7
GND: C201.2, C202.2, C203.-, C204.2, C205.2, C206.2, C207.2, IC201.2 (GND), LED201.C, LED202.C, SV201.1, SV202.2, SV202.4, SV202.6, SV202.8, SV203.2, SV203.4, SV203.6, SV204.2, SV204.4, SV204.6; also elsewhere on the board
unnamed: LED202.A, R202.2
unnamed: LED201.A, R201.2

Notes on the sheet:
SV201: +12VDC input SV202: To HV supply SV203-204: Regulated 5V



Board: 2 copper layers, 97.0 x 38.1 mm, 32 parts (9 on the bottom side), 24 nets.

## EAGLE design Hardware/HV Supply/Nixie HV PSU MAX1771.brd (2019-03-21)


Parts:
C1: 100uF,35V; C-EIA-7343; MOUSER 581-TPSD107M020R0085
C2, C3: 100n; C0805; MOUSER 80-C0805C104M4V
C4: 4u7,250V; NICHICON-UJ-12; MOUSER 667-EEV-EB2E100Q
C5: 10uF,25V; C-EIA-7343; MOUSER 581-TPSD106K035R0300
C6: 100n,250V; C2420; MOUSER 667-ECW-U2104KC9
D1: ES2F; SMC; MOUSER 821-ES2FR5
IC1: MAX1771ESA; SO-8; MOUSER 700-MAX1771ESAT
J3: TERM-BLOCK-2-02IN; SCREW-2-02
L1: 100uH; L-B82479; MOUSER 871-B82479A1104M
R1: 10K; R0805; MOUSER 71-CRCW080510K0FKEAC
R2: 1M5; R2512; MOUSER 279-35221M5JT
RSENSE: 0R050; R2010; MOUSER 66-LR2010LF-01-R050
SV202: MA04-2
T1: IRF644PBF; TO220BV; MOUSER 844-IRF644PBF
VR1: 5K; BOURNS-3214W; MOUSER 652-3214W-1-502E

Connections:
+5V: SV202.1
+12V: C1.+, C2.1, C5.+, IC1.2 (VCC), L1.P$1 (1), SV202.3, SV202.5, SV202.7
DGND: C1.-, C2.2, C3.2, C4.1 (-), C5.-, C6.P$2 (2), IC1.6 (AGND), IC1.7 (GND), J3.1, R1.1, RSENSE.1, SV202.4, SV202.6, SV202.8
EXT: IC1.1 (EXT), T1.G
unnamed: IC1.8 (CS), RSENSE.2, T1.S
unnamed: R1.2, VR1.1 (A), VR1.2 (W)
unnamed: IC1.3 (FB), R2.1, VR1.3 (B)
unnamed: D1.A, L1.P$2 (2), T1.D
unnamed: C3.1, IC1.5 (REF)
SHDN: IC1.4 (SHDN), SV202.2
VOUT: C4.2 (+), C6.P$1 (1), D1.C, J3.2, R2.2

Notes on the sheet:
R2, C4, C6 must be rated at > 220V operating
D1 should be an ultra-fast (<50nS) recovery, 1A 220V
C1 & C5 should be a low ESR type (e.g. AVX TPS series)
C2 & C5 should be sited very close to pin 2 (Vcc) of IC1
Nick de Smith
VR1 adjusts Vout between 150V and 220V and should be multi-turn for more accurate adjustment
C4 should be low ESR (< 3ohms) and rated > 220V
If you have stability issues, a 100p 250V ceramic cap could be soldered on top of R2
L1 should be 2A rated (e.g. EPCOS B82479 series) for 50mA output
Join J1-1 & J1-2 to Vcc (9-16V)
Join J2-1 & J2-2 to GND
T1 should be selected for low Qg, Rdson & Coss.
Rsense MUST be capable of handling at least 2A
High Efficiency (typically 85%) 50mA, 150-220V, Nixie Power Supply
If PWR > 15V, use a seperate supply (e.g. via a 78L12) for Vcc
Note: The physical board layout is critical in order to obtain high efficiency
If you only want 25mA output, you can use a 1A inductor for L1 (e.g. a CDRH125-101) and 0R100 for Rsense


Board: 2 copper layers, 51.5 x 42.0 mm, 19 parts (0 on the bottom side), 10 nets.

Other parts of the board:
U$2, U$3, U$4: 2,8

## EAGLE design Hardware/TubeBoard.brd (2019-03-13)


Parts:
C1, C2, C3, C4, C5: 100nF; C1206
C8: 10µF; SMC_B; MOUSER 581-TAJB106K020RNJV
DISP1, DISP2: DISP_IN12A; DISP_IN-12_SOCKET
H1, H2, H3, H4: MOUNT-HOLE2.8; 2,8
IC1, IC2: 74HC373DW; SO20W
IC3: 74HC85D; SO16; MOUSER 771-74HC85D-T
IC4: 74HC04D; SO14
IC5: 74HC08D; SO14
IC6, IC7: 7441DIL16; DIL16
R1, R2: 15k; 0411/12
R3, R4: 174k; M1206; MOUSER 667-ERJ-8ENF1743V
R5, R6, R7, R8, R9: 10k; R2012; MOUSER 652-CR0805FX-1002ELF
S1: SD4-03; MOUSER 611-BDB03
SV1: MA03-1
SV2: MA10-2
T1, T2: MPSA42; TO92-EBC; MOUSER 833-MPSA42-AP
U$1, U$2: INS-1

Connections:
1_K0: DISP1.2 (K0), IC6.16 (OUT0)
1_K1: DISP1.11 (K1), IC6.15 (OUT1)
1_K2: DISP1.10 (K2), IC6.8 (OUT2)
1_K3: DISP1.9 (K3), IC6.9 (OUT3)
1_K4: DISP1.8 (K4), IC6.13 (OUT4)
1_K5: DISP1.7 (K5), IC6.14 (OUT5)
1_K6: DISP1.6 (K6), IC6.11 (OUT6)
1_K7: DISP1.5 (K7), IC6.10 (OUT7)
1_K8: DISP1.4 (K8), IC6.1 (OUT8)
1_K9: DISP1.3 (K9), IC6.2 (OUT9)
2_K0: DISP2.2 (K0), IC7.16 (OUT0)
2_K1: DISP2.11 (K1), IC7.15 (OUT1)
2_K2: DISP2.10 (K2), IC7.8 (OUT2)
2_K3: DISP2.9 (K3), IC7.9 (OUT3)
2_K4: DISP2.8 (K4), IC7.13 (OUT4)
2_K5: DISP2.7 (K5), IC7.14 (OUT5)
2_K6: DISP2.6 (K6), IC7.11 (OUT6)
2_K7: DISP2.5 (K7), IC7.10 (OUT7)
2_K8: DISP2.4 (K8), IC7.1 (OUT8)
2_K9: DISP2.3 (K9), IC7.2 (OUT9)
!A0: IC4.4 (O), IC5.5 (I1)
!NIXIE_CS: IC4.1 (I), SV2.17
+5V: C1.1, C2.1, C3.1, C4.1, C5.1, C8.+, IC1.20 (VCC), IC2.20 (VCC), IC3.3 (A=B_I), IC3.16 (VCC), IC4.14 (VCC), IC5.14 (VCC), IC6.5 (VCC), IC7.5 (VCC), S1.1, S1.2, S1.3, SV2.19
A0: IC4.3 (I), IC5.2 (I1), SV2.3
A1: SV2.5
A2: IC3.10 (A0), SV2.7
A3: IC3.12 (A1), SV2.9
A4: IC3.13 (A2), SV2.11
BOARD_SELECT: IC5.1 (I0), IC5.4 (I0), IC5.8 (O)
COLON_B: IC2.2 (1Q), R8.1
COLON_T: IC2.5 (2Q), R9.1
CONTROL_LATCH: IC2.11 (ENC), IC5.3 (O)
D0: IC1.3 (1D), IC2.3 (1D), SV2.8
D1: IC1.4 (2D), IC2.4 (2D), SV2.6
D2: IC1.7 (3D), IC2.7 (3D), SV2.4
D3: IC1.8 (4D), IC2.8 (4D), SV2.10
D4: IC1.13 (5D), IC2.13 (5D), SV2.12
D5: IC1.14 (6D), IC2.14 (6D), SV2.14
D6: IC1.17 (7D), IC2.17 (7D), SV2.16
D7: IC1.18 (8D), IC2.18 (8D), SV2.18
DIGIT_LATCH: IC1.11 (ENC), IC5.6 (O)
DRIVE_HI: IC2.19 (8Q)
DRIVE_LO: IC2.15 (6Q)
DRIVE_MED: IC2.16 (7Q)
GND: C1.2, C2.2, C3.2, C4.2, C5.2, C8.-, IC1.1 (OC), IC1.10 (GND), IC2.1 (OC), IC2.10 (GND), IC3.1 (B3), IC3.2 (A<B_I), IC3.4 (A>B_I), IC3.8 (GND), IC3.15 (A3), IC4.7 (GND), IC5.7 (GND), IC6.12 (GND), IC7.12 (GND), R5.2, R6.2, R7.2, SV1.1, SV1.3, SV2.1, SV2.2, SV2.20, T1.E, T2.E
HV_ANODE: R1.2, R2.2, R3.1, R4.1, SV1.2
ID0: IC3.9 (B0), R7.1, S1.6
ID1: IC3.11 (B1), R6.1, S1.5
ID2: IC3.14 (B2), R5.1, S1.4
K_COLON_B: T1.C, U$2.C
K_COLON_T: T2.C, U$1.C
LDIGIT0: IC1.2 (1Q), IC6.3 (A)
LDIGIT1: IC1.5 (2Q), IC6.6 (B)
LDIGIT2: IC1.6 (3Q), IC6.7 (C)
LDIGIT3: IC1.9 (4Q), IC6.4 (D)
unnamed: DISP1.1 (ANODE), R1.1
unnamed: DISP2.1 (ANODE), R2.1
unnamed: R3.2, U$1.A
unnamed: R4.2, U$2.A
unnamed: R8.2, T1.B
unnamed: R9.2, T2.B
NIXIE_CS: IC4.2 (O), IC5.9 (I0)
RDIGIT0: IC1.12 (5Q), IC7.3 (A)
RDIGIT1: IC1.15 (6Q), IC7.6 (B)
RDIGIT2: IC1.16 (7Q), IC7.7 (C)
RDIGIT3: IC1.19 (8Q), IC7.4 (D)
SELECT_EN: IC3.6 (A=B_O), IC5.10 (I1)

Board: 2 copper layers, 35 parts (4 on the bottom side), 63 nets, no tracks yet.

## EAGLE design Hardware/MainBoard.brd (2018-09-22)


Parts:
C1: 4.7uF 250V; E3,5-8
C3: 1uF; C0603
C4: 100nF; C0603
C5: 2.2uF; C1206
C6: 150nF; C0603
C7: 100pF; C0603
C8: 100µF; CT7343; MOUSER 581-NOSD107M006
C9: 10uF; C1206
C10, C20: 100uF; E2,5-6
C11: 100pF 250V; C1812
C12: 330pF; C0603
C13: 470pF; C0603
C15, C17: 100nF; C0805; MOUSER 710-885012207072
C16: 100nF 250V X2; C102_152-062X184
C19: 100uF; E3,5-8
D1: ES2G; DO-214AC
IC1: TPS40210DGQ; MSOP10
J1: DCJ0303
L1: 47uH; DR125
L3: 22µH; SRR1050A; MOUSER 652-SRR1050A-220Y
LED1, LED5: LEDCHIPLED_1206; CHIPLED_1206; MOUSER 604-APTR3216SGC
LP1, LP2, LP3: 3,17/1,3
R1, R2: 5.6k; M0805; MOUSER 652-CR0805FX-5601ELF
R1-1, R1-2: 150k; R0805
R2-1, R6: 1k; R0603
R2-2: 150R; R0603
R3: 240k; R0603
R4: 620k; R0603
R5-1, R5-2: 0R100; R1206
R7: 3R3; R0805
R14: 1.5k; M0805; MOUSER 652-CR0805FX-1501ELF
T1: IRFH5025PBF; PQFN5X6
TP1, TP2, TP3: TPTP08SQ; TP08SQ
U$2: FERYSTER-DSZ-10-R5; DSZ-10-R5

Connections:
!HV_EN: IC1.P$3 (!EN), R2.2; also elsewhere on the board
+5V: C8.+, C17.1, L3.P$2 (2), R2.1, R14.1; also elsewhere on the board
+12V: C4.1, C9.1, C10.+, C15.1, C19.+, C20.+, IC1.P$10 (VDD), J1.1, L1.2, LP1.1, LP3.1, R1.1, R4.2, U$2.P2; also elsewhere on the board
COMP: C6.1, C7.1, IC1.P$4 (COMP)
D: R5-1.2, R5-2.2, R6.2, T1.S1 (S), T1.S2 (S), T1.S3 (S), T1.S4 (S)
FB: C7.2, IC1.P$5 (FB), R1-1.1, R2-2.2, R3.1, TP1.TP
GDRV: IC1.P$8 (GDRV), T1.G, TP2.TP
GND: C1.-, C3.2, C4.2, C5.2, C8.-, C9.2, C10.-, C12.2, C13.2, C16.2, C16.3, C17.2, C19.-, C20.-, IC1.P$6 (GND), IC1.PWRPAD, J1.2, J1.3, LED1.C, LED5.C, R2-1.1, R5-1.1, R5-2.1, R7.1; also elsewhere on the board
HV: C1.+, C16.1, D1.C, R1-2.2; also elsewhere on the board
unnamed: LED5.A, R14.2
unnamed: LED1.A, R1.2
unnamed: R1-1.2, R1-2.1
unnamed: C13.1, IC1.P$1 (RC), R4.1, TP3.TP
unnamed: C3.1, IC1.P$9 (BP)
unnamed: C6.2, R3.2
unnamed: R2-1.2, R2-2.1
unnamed: C5.1, IC1.P$2 (SS)
unnamed: C11.2, R7.2
PULSE: C11.1, D1.A, L1.1, LP2.1, T1.D1 (D), T1.D2 (D), T1.D3 (D), T1.D4 (D), T1.D5 (D), U$2.P1
SNS: C12.1, IC1.P$7 (ISNS), R6.1

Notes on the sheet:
Only one mandatory (two case variants)
C20 is optional, normally not needed
Inductor case variants
IRFH5025TR2PBF
Based on Jan Rychter's HV PSU 2.3 https://jan.rychter.com/high-voltage-power-supply-for-nixie-tube-projects


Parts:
SV1, SV2, SV3, SV5: MA10-2
SV4: FE20-2

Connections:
!HV_EN: SV4.24; also elsewhere on the board
!K_BLANK: SV1.14, SV2.14, SV3.14, SV4.36, SV5.14
!K_LATCH: SV1.15, SV2.15, SV3.15, SV4.22, SV5.15
+5V: SV1.11, SV2.11, SV3.11, SV4.2, SV4.4, SV5.11; also elsewhere on the board
+12V: SV1.9, SV2.9, SV3.9, SV5.9; also elsewhere on the board
GND: SV1.2, SV1.4, SV1.6, SV1.8, SV1.10, SV1.12, SV2.2, SV2.4, SV2.6, SV2.8, SV2.10, SV2.12, SV3.2, SV3.4, SV3.6, SV3.8, SV3.10, SV3.12, SV4.6, SV4.9, SV4.20, SV4.25, SV4.30, SV4.34, SV4.39, SV5.2, SV5.4, SV5.6, SV5.8, SV5.10, SV5.12; also elsewhere on the board
HV: SV1.1, SV1.3, SV1.5, SV2.1, SV2.3, SV2.5, SV3.1, SV3.3, SV3.5, SV5.1, SV5.3, SV5.5; also elsewhere on the board
I2C_SCL: SV4.5
I2C_SDA: SV4.3
K_CLK: SV1.16, SV2.16, SV3.16, SV4.40, SV5.16
K_DIN: SV1.18, SV4.38
K_DOUT1: SV1.17, SV2.18
K_DOUT2: SV2.17, SV3.18
K_DOUT3: SV3.17, SV5.18
K_DOUT4: SV5.17
LED_DIN: SV1.20, SV4.12
LED_DOUT1: SV1.19, SV2.20
LED_DOUT2: SV2.19, SV3.20
LED_DOUT3: SV3.19, SV5.20
LED_DOUT4: SV5.19

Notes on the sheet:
Raspberry Pi Connector


Board: 2 copper layers, 70.0 x 54.0 mm, 51 parts (1 on the bottom side), 31 nets.

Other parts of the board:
U$5: DANGER-SIGN-1X

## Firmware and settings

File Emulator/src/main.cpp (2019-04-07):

/**
 * Entry point for the emulator; this parses command line parameters and sets up
 * the state of the rest of the emulator.
 */
#include <unistd.h>

#include <iostream>
#include <string>

#include <glog/logging.h>

#include "Emulator.h"


static void SetUpLogging(int argc, char const *argv[]);

static int ParseCommandLine(int argc, char const *argv[]);
static void PrintUsage(const char *binName);

/**
 * File paths and whatnot
 */
static struct {
	// location of rom file
	std::string romPath = "rom.bin";
	// location of NVRAM file
	std::string nvramPath = "nvram.bin";
} gState;


/**
 * Entry point
 */
int main(int argc, char const *argv[]) {
	int err;

	// parse command line options; exit if returns less than 1
	err = ParseCommandLine(argc, argv);

	if(err <= 0) {
		return err;
	}

	// early setup
	SetUpLogging(argc, argv);


	// set up CPU emulation
	Emulator *emu = new Emulator(gState.romPath, gState.nvramPath);

	// start
	emu->start();

	// clean up
	delete emu;

  return 0;
}



/**
 * Sets up logging.
 */
static void SetUpLogging(int argc, char const *argv[]) {
	// set up logging
	FLAGS_logtostderr = 1;
	FLAGS_colorlogtostderr = 1;

#if DEBUG
	FLAGS_v = 2;
#else
	FLAGS_v = 0;
#endif

	google::InitGoogleLogging(argv[0]);
	google::InstallFailureSignalHandler();

	LOG(INFO) << "nixieclock_emu " << GIT_HASH << "/" << GIT_BRANCH
			  << " compiled on " << COMPILE_TIME;
}

/**
 * Parses the command line.
 */
static int ParseCommandLine(int argc, char const *argv[]) {
	int c;

	while((c = getopt(argc, const_cast<char **>(argv), "hr:n:")) != -1) {
		switch(c) {
			case 'h':
				PrintUsage(argv[0]);
				return 0;

				// boot rom file
				case 'r':
					gState.romPath = std::string(optarg);
					break;

				// nvram shadow file
				case 'n':
					gState.nvramPath = std::string(optarg);
					break;

				// something went wrong
				case '?':
				// case ':':
					return -1;
			}
	}

	// assume success
	return 1;
}

/**
 * Prints the usage instructions.
 */
static void PrintUsage(const char *binName) {
	// print to cout, not log
	std::cout << "usage: " << binName << "[-r rom] [-n nvram] -h" << std::endl;
	std::cout << "\t-r: Path to boot ROM file" << std::endl;
	std::cout << "\t-n: Path to NVRAM file" << std::endl;
	std::cout << "\t-h: Displays help on using this program" << std::endl;
	std::cout << std::endl;
	std::cout << "git version " << GIT_HASH << "/" << GIT_BRANCH << std::endl;
}

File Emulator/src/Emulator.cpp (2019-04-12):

#include "Emulator.h"

#include "MC68681.h"
#include "TubeDrivers.h"
#include "VFD.h"
#include "DS1244.h"

#include <string>
#include <vector>
#include <sstream>
#include <iostream>
#include <iomanip>
#include <fstream>
#include <stdexcept>
#include <cstdint>

#include <glog/logging.h>

extern "C" {
  #include "musashi/m68k.h"
}

/// Should all instructions be logged?
#define LOG_INSTRUCTIONS        0
/// should we log memory accesses?
#define LOG_MEM_READ            0
#define LOG_MEM_WRITE           0


static Emulator *gEmulator = nullptr;



extern "C" void m68k_instruction_hook(void);
extern "C" void m68k_reset_called(void);



/**
 * Sets up the emulator.
 */
Emulator::Emulator(std::string romFilePath, std::string nvramFilePath) {
  // ensure we haven't already been allocated
  CHECK(gEmulator == nullptr) << "Already have an allocated emulator";
  gEmulator = this;

  // initialize peripherals
  this->duart = new MC68681(this);
  this->tubes = new TubeDrivers(this);
  this->vfd = new VFD(this);
  this->rtc = new DS1244(this, this->nvram);

  // load ROM
  this->loadROM(romFilePath);

  // set up CPU
  m68k_init();
	m68k_set_cpu_type(M68K_CPU_TYPE_68000);
  m68k_set_instr_hook_callback(m68k_instruction_hook);
  m68k_set_reset_instr_callback(m68k_reset_called);

  m68k_pulse_reset();
}


/**
 * Tears down the emulator.
 */
Emulator::~Emulator() {
  // clean up peripherals
  if(this->duart) {
    delete this->duart;
    this->duart = nullptr;
  }

  if(this->tubes) {
    delete this->tubes;
    this->tubes = nullptr;
  }

  if(this->vfd) {
    delete this->vfd;
    this->vfd = nullptr;
  }

  if(this->rtc) {
    delete this->rtc;
    this->rtc = nullptr;
  }
}



/**
 * Loads the ROM file from disk.
 */
void Emulator::loadROM(const std::string path) {
  memset(this->memRom, 0xFF, sizeof(this->memRom));

  // read file
  VLOG(1) << "Reading ROM from `" << path << "`";
  std::fstream romFile(path, std::ios::in | std::ios::binary | std::ios::ate);

  if(!romFile.is_open()) {
    throw std::runtime_error("Couldn't open ROM file at " + path);
  }

  std::streamsize size = romFile.tellg();
  romFile.seekg(0, std::ios::beg);

  std::vector<char> rom(size);
  if(romFile.read(rom.data(), size)) {
    // write it into memory now
    memcpy(this->memRom, rom.data(), size);

    // also, extract stack and PC and set that
    this->initialSp = __builtin_bswap32(*((uint32_t *) rom.data()));
    this->initialPc = __builtin_bswap32(*((uint32_t *) (rom.data() + 4)));

    // m68k_set_reg(M68K_REG_PC, this->initialPc);
    // m68k_set_reg(M68K_REG_SP, this->initialSp);

    LOG(INFO) << "Initial PC = $" << std::hex << this->initialPc
              << "; stack = $" << this->initialSp << std::endl;
  } else {
    throw std::runtime_error("Couldn't read ROM file to memory");
  }

  // done
  romFile.close();
}

/**
 * Loads NVRAM from disk.
 */
void Emulator::loadNVRAM(const std::string path) {
  // TODO: implement this
}


/**
 * Dumps the registers from the CPU.
 */
void Emulator::getRegs(M68kRegs &regs) {
  // dump registers
  const size_t numRegs = 18;

  const m68k_register_t regIds[numRegs] = {
    M68K_REG_D0, M68K_REG_D1, M68K_REG_D2, M68K_REG_D3,
    M68K_REG_D4, M68K_REG_D5, M68K_REG_D6, M68K_REG_D7,

    M68K_REG_A0, M68K_REG_A1, M68K_REG_A2, M68K_REG_A3,
    M68K_REG_A4, M68K_REG_A5, M68K_REG_A6, M68K_REG_A7,

    M68K_REG_PC, M68K_REG_SR
  };
  uint32_t *regVals[numRegs] = {
    &regs.d0, &regs.d1, &regs.d2, &regs.d3,
    &regs.d4, &regs.d5, &regs.d6, &regs.d7,

    &regs.a0, &regs.a1, &regs.a2, &regs.a3,
    &regs.a4, &regs.a5, &regs.a6, &regs.a7,

    &regs.pc, &regs.sr
  };

  for(int i = 0; i < numRegs; i++) {
    // read reg
    *regVals[i] = m68k_get_reg(nullptr, regIds[i]);
  }
}


/**
 * Starts emulation.
 */
void Emulator::start(void) {
  while(this->run) {
    // run weed processor
    m68k_execute(100000);
  }
}

/**
 * Stops emulation.
 */
void Emulator::stop(void) {
  this->run = false;
}



/**
 * Instruction executed hook
 */
void Emulator::cpuExecutedInstruction(uint64_t address) {
#if LOG_INSTRUCTIONS
  // disassemble
  char instrBuffer[48];
  memset(&instrBuffer, 0, sizeof(instrBuffer));

  int count = m68k_disassemble(instrBuffer, address, M68K_CPU_TYPE_68000);

  // log instruction and registers
  Emulator::M68kRegs regs;
  this->getRegs(regs);

  VLOG(2) << "TRACE: address = $" << std::hex << address << ": " << std::string(instrBuffer) << std::endl << regs;
#endif
}

/**
 * Memory access hook
 */
void Emulator::cpuHookMem(bool read, uint64_t addr, int size, int64_t value) {
  VLOG(2) << "MEM: " << (read ? "read" : "write") << " at address $" << std::hex << addr << ", size $" << size;
}

/**
 * Interrupt hook
 */
void Emulator::cpuInt(uint32_t intno) {
  if(intno == 61) {
    LOG(ERROR) << "Unsupported exception: " << intno;
    exit(-1);
  }

  LOG(INFO) << "Interrupt: " << intno;
}




/**
 * Outputs a register structure.
 */
std::ostream& operator<<(std::ostream& os, const Emulator::M68kRegs& regs) {
  // set up a temporary stream
  std::stringstream ss;
  ss << std::setfill('0') << std::right << std::hex
     << "D0: $" << std::setw(8) << regs.d0 << "\t"
     << "D1: $" << std::setw(8) << regs.d1 << std::endl
     << "D2: $" << std::setw(8) << regs.d2 << "\t"
     << "D3: $" << std::setw(8) << regs.d3 << std::endl
     << "D4: $" << std::setw(8) << regs.d4 << "\t"
     << "D5: $" << std::setw(8) << regs.d5 << std::endl
     << "D6: $" << std::setw(8) << regs.d6 << "\t"
     << "D7: $" << std::setw(8) << regs.d7 << std::endl
     << "A0: $" << std::setw(8) << regs.a0 << "\t"
     << "A1: $" << std::setw(8) << regs.a1 << std::endl
     << "A2: $" << std::setw(8) << regs.a2 << "\t"
     << "A3: $" << std::setw(8) << regs.a3 << std::endl
     << "A4: $" << std::setw(8) << regs.a4 << "\t"
     << "A5: $" << std::setw(8) << regs.a5 << std::endl
     << "A6: $" << std::setw(8) << regs.a6 << "\t"
     << "A7: $" << std::setw(8) << regs.a7 << std::endl
     << "PC: $" << std::setw(8) << regs.pc << "\t"
     << "SR: $" << std::setw(8) << regs.sr << std::endl;

  // print the buffer
  os << ss.str();

  return os;
}



/**
 * Returns the address of read/write buffers for fixed memories like ROM and
 * RAM.
 */
void *Get68kBuffer(bool isRead, uint32_t addr) {
  // limit address to 512K
  addr &= 0x07FFFF;

  // is this read access?
  if(isRead) {
    // ROM
    if(addr < 0x020000) {
      return &gEmulator->memRom[addr];
    }
    // RAM?
    else if(addr >= 0x060000 && addr < 0x07FFFF) {
      return &gEmulator->memRam[(addr - 0x060000)];
    }
  }
  // otherwise, it's a write
  else {
    // RAM?
    if(addr >= 0x060000 && addr < 0x07FFFF) {
      return &gEmulator->memRam[(addr - 0x060000)];
    }
  }

  // no success
  return nullptr;
}
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

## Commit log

2018-09-15 added shift register-based nixie driver
    [TubeBoard.brd, TubeBoard.sch]
2018-09-15 Finished routing tube board
    [TubeBoard.brd, TubeBoard.sch]
2018-09-15 Added colons
    [TubeBoard.brd, TubeBoard.sch]
2018-09-22 add main board
    [MainBoard.brd, MainBoard.sch]
2018-12-14 Began work on 68k-based nixie clock
    [NixieClock_68k.sch]
2019-03-05 move files around
    [MainBoard.brd, MainBoard.sch, NixieClock_68k.sch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]
2019-03-06 Replaced 68681 with FT245R; added header for VFD
    [NixieClock_68k.sch]
2019-03-06 basic address decoding
    [NixieClock_68k.sch]
2019-03-06 use cpld for all system logic
    [NixieClock_68k.sch]
2019-03-06 replaced SRAM with DIP variant
    [NixieClock_68k.sch]
2019-03-06 start board layout
    [NixieClock_68k.brd, NixieClock_68k.sch]
2019-03-07 more progress routing board
    [NixieClock_68k.brd, NixieClock_68k.sch]
2019-03-07 added some more missing pull resistors for usb
    [NixieClock_68k.brd, NixieClock_68k.sch]
2019-03-07 more routing of address bus
    [NixieClock_68k.brd, NixieClock_68k.sch]
2019-03-07 cleaned up routing of busses for memories
    [NixieClock_68k.brd]
2019-03-07 replaced cpld with ttl logic
    [NixieClock_68k.brd, NixieClock_68k.sch]
2019-03-07 routed most system control signals
    [NixieClock_68k.brd, NixieClock_68k.sch]
2019-03-11 routed 68681 data bus, some chip selects
    [NixieClock_68k.brd, NixieClock_68k.sch]
2019-03-12 finished routing main board
    [NixieClock_68k.brd, NixieClock_68k.sch]
2019-03-12 added missing pull-ups to ROM and RAM CS; 68681 DTACK
    [NixieClock_68k.brd, NixieClock_68k.sch]
2019-03-12 finished tube board schematic
    [NixieClock_68k.brd, TubeBoard.brd, TubeBoard.sch]
2019-03-13 added transistors to drive colons
    [TubeBoard.brd, TubeBoard.sch]
2019-03-13 separated tubes and logic on two separate boards
    [TubeBoard-Holder.brd, TubeBoard-Holder.sch, TubeBoard-Logic.brd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]
2019-03-14 routed tube logic board
    [TubeBoard-Logic.brd, TubeBoard-Logic.sch]
2019-03-14 added data bus resistors; better reset circuit
    [NixieClock_68k.brd, NixieClock_68k.sch, TubeBoard-Logic.brd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]
2019-03-15 basic 68681 initialization; more nixie driver routines and ram defines
    [NixieClock_68k.brd, NixieClock_68k.sch]
2019-03-15 tied unused logic on tube board logic board to ground
    [TubeBoard-Logic.brd, TubeBoard-Logic.sch]
2019-03-15 updated rom/ram chip select logic
    [NixieClock_68k.brd, NixieClock_68k.sch]
2019-03-17 revamped power connections; moved power regulation to separate board (plus RS232 conversion)
    [NixieClock_68k.brd, PowerBoard.brd, PowerBoard.sch]
2019-03-21 Added HV supply; cleaned up power board
    [Nixie HV PSU MAX1771.brd, Nixie HV PSU MAX1771.sch, PowerBoard.brd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]
2019-03-26 added ARM chip to driver boards to PWM tubes
    [PowerBoard.brd, TubeBoard-Holder.brd, TubeBoard-Holder.sch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]
2019-03-28 added pwm drivers to tube board
    [TubeBoard-Holder.brd, TubeBoard-Holder.sch]
2019-04-01 more uart stuff in loader
    [NixieClock_68k.brd, NixieClock_68k.sch]
2019-04-05 basic app and updated checksum handling
    [NixieClock_68k.brd, TubeBoard-Logic.sch]
2019-04-07 more work for vfd command handling
    [NixieClock_68k.sch, TubeBoard-Logic.brd, TubeBoard-Logic.sch]
2019-04-07 switch to using musashi for 68k emulation
2019-04-08 Fixed bug preventing output in loader; began work on 68681 emulation
    [Emulator.cpp, MC68681.cpp, MC68681.h]
2019-04-10 semi functional 68681 emulation (enough to get UART A working)
2019-04-10 use RESET as a software interrupt
    [Emulator.cpp]
2019-04-11 basic tube drivers IO
2019-04-21 more routing of tube logic board
    [TubeBoard-Logic.brd, TubeBoard-Logic.sch]
2019-04-28 finished routing basic data latch only tube logic board
    [TubeBoard-Logic.brd, TubeBoard-Logic.sch]

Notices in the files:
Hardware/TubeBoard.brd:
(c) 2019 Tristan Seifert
